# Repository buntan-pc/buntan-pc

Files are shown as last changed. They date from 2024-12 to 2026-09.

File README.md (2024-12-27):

# buntan-pc
BuntanPC は CPU・OS・言語処理系を手作りするプロジェクトです

## プロジェクトの目的
プロジェクトの主目的はオリジナルのコンピュータを作り上げることです。
その過程で CPU、OS、コンパイラ、アセンブラ、リンカ等の作り方を学ぶという副目的もあります。

最終的に BuntanPC で文書作成や Web 閲覧、ロボット制御、プログラミングなどをしたいです。

開発は当面パソコン上で行い、ビルド済みプログラムを転送して実行しますが、
最終的には BuntanPC 上で BuntanPC 向けのアプリを開発したいです。

### マイルストーン
[プロジェクトの中間目標](./doc/milestone.md) には展示会やイベントなどを対象とした開発目標を記します。

## 名前の由来
柑橘類の「文旦（ぶんたん）」と、役割「分担」して作るという意味を掛けています。

PC は Pocket Computer もしくは Personal Computer の略です。
最初はきっとポケコン的な見た目や機能になると思います。
最終的にパソコンが作れたら楽しいですね。

## ライセンス
buntan-pc リポジトリに含まれるソースコードやドキュメントは、別に定めがない限り MIT ライセンスとします。
ライセンス文書 [LICENSE](./LICENSE) にしたがってご利用ください。

## ビルド・実行
実際のビルド方法が決まったらここに書きます。

当面は CPU と OS は BuntanPC Board で動かし、コンパイラ等の言語処理系はパソコン上で動かすことを想定しています。

## BuntanPC Board
BuntanPC を動かすための実機です。
オリジナルのプリント基板を使ったポケコン風の装置で、キーボードや表示装置を持ちます。

プリント基板の提供方法は未定です。決まったら書きます。

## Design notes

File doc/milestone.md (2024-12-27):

# プロジェクトの中間目標

## 2/21 OSC2025 Tokyo/Spring

2/21、22 に開催される [OSC2025 Tokyo/Spring](https://event.ospn.jp/osc2025-spring/) に展示したい。

最低限、次の状態を達成したい！

- BuntanPC 上で何らかの「テキストエディタ」が動き、ファイルを SD カードに保存できる。
  - UART で入出力する前提なので、GUI ではなく CUI あるいは TUI。
  - 最低限は、コマンドラインで 1 行だけ書き込めるもの。
    - 例えば `writestr file.txt foobar hogera` とすると「foobar hogera」とファイルに書かれるとか。
  - Vi のように画面があり、カーソルが動きまわるエディタが作れたら最高。
    - スクロールできない（スクロールせず扱える行数しか扱えない）という仕様もアリ。

可能なら、次の状態も達成したい。

- HEX ファイルを読み取って pmem へ転送し、実行できる。
  - 上述のテキストエディタと組み合わせると、BuntanPC 上でプログラミングできる。
  - ただしハンドアセンブル必須。
- 音楽ファイルを読み取ってスピーカで再生できる。
  - MML のような音楽情報が書かれたファイルを想定。
  - GPIO に接続された圧電スピーカを用いて音楽を再生する。

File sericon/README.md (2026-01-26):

# BuntanPC 用シリアルコンソール

ファイル構成

    controller_rev1/    メインコントローラ（Tang Nano 9K）のソースコードなど

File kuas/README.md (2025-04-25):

= kuas

川合氏作成のアセンブラです。
「kuas」の名前の由来は川合（K）が作った uas 互換アセンブラということです。

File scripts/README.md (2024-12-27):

# scripts

原則として 1 ファイルで完結する、互いに依存しない小物ツール専用のディレクトリです。

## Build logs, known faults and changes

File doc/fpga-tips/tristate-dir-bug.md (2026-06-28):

# USB デバイス検出が動作しないバグ

## 症状

USB の D+/D- を使って USB デバイスの接続を検出しようとしたが、デバイスを接続しても検出されない。

### 具体的説明

次のようなコードを書いたとき、`onboard_led` が点灯しなかった。（LED は 0 出力で点灯）
想定では下位 2 ビットが USB デバイスのスピードに応じて点灯するはずだった。

```veryl
var usb_dp : 'usb logic; // usb_clk に同期した USB D+ 信号
var usb_dm : 'usb logic; // usb_clk に同期した USB D- 信号

var usb_dir_out : 'usb bit;
var usb_dp_out : 'usb logic;
var usb_dm_out : 'usb logic;
assign usb_dp_raw = if usb_dir_out ? usb_dp_out : 1'bz;
assign usb_dm_raw = if usb_dir_out ? usb_dm_out : 1'bz;

enum USBDevSpeed: bit<2> {
  None,
  LS,
  FS,
}
var usb_dev_speed : 'usb USBDevSpeed;

always_ff (usb_clk, usb_rst_n) {
  if_reset {
    usb_dev_speed = USBDevSpeed::None;
  } else if (usb_dm) {
    usb_dev_speed = USBDevSpeed::LS;
  } else if (usb_dp) {
    usb_dev_speed = USBDevSpeed::FS;
  }
}

unsafe (cdc) {
  assign onboard_led = {if ~usb_rst_n ? 4'b0000 : 4'b1111, ~usb_dev_speed};
}
```

## 原因

`usb_dir_out`（USB ライン送受信の方向制御）が未初期化だった。

```veryl
var usb_dir_out : 'usb bit;  // ドライバなし

assign usb_dp_raw = if usb_dir_out ? usb_dp_out : 1'bz;
assign usb_dm_raw = if usb_dir_out ? usb_dm_out : 1'bz;
```

Gowin の合成ツールが未ドライブの `logic` を 0 に最適化せず、`usb_dir_out = 1` であるかのように動作した。その結果 D+/D- が 0 にドライブされた。`usb_dp` と `usb_dm` が 0 として読み出され、`usb_dev_speed` が `None` から更新されなかった。

## 解決策

`usb_dir_out` を明示的に 0 （受信モード）に設定してから D+/D- を読む。
試験的に `assign` で 0 に固定したところ、LED が光るようになった。

```veryl
assign usb_dir_out = 0;
```

## 教訓

双方向 I/O の方向制御信号は必ず明示的に初期化する。
未ドライブの配線/レジスタが合成ツールによって 0 と扱われるとは限らない。

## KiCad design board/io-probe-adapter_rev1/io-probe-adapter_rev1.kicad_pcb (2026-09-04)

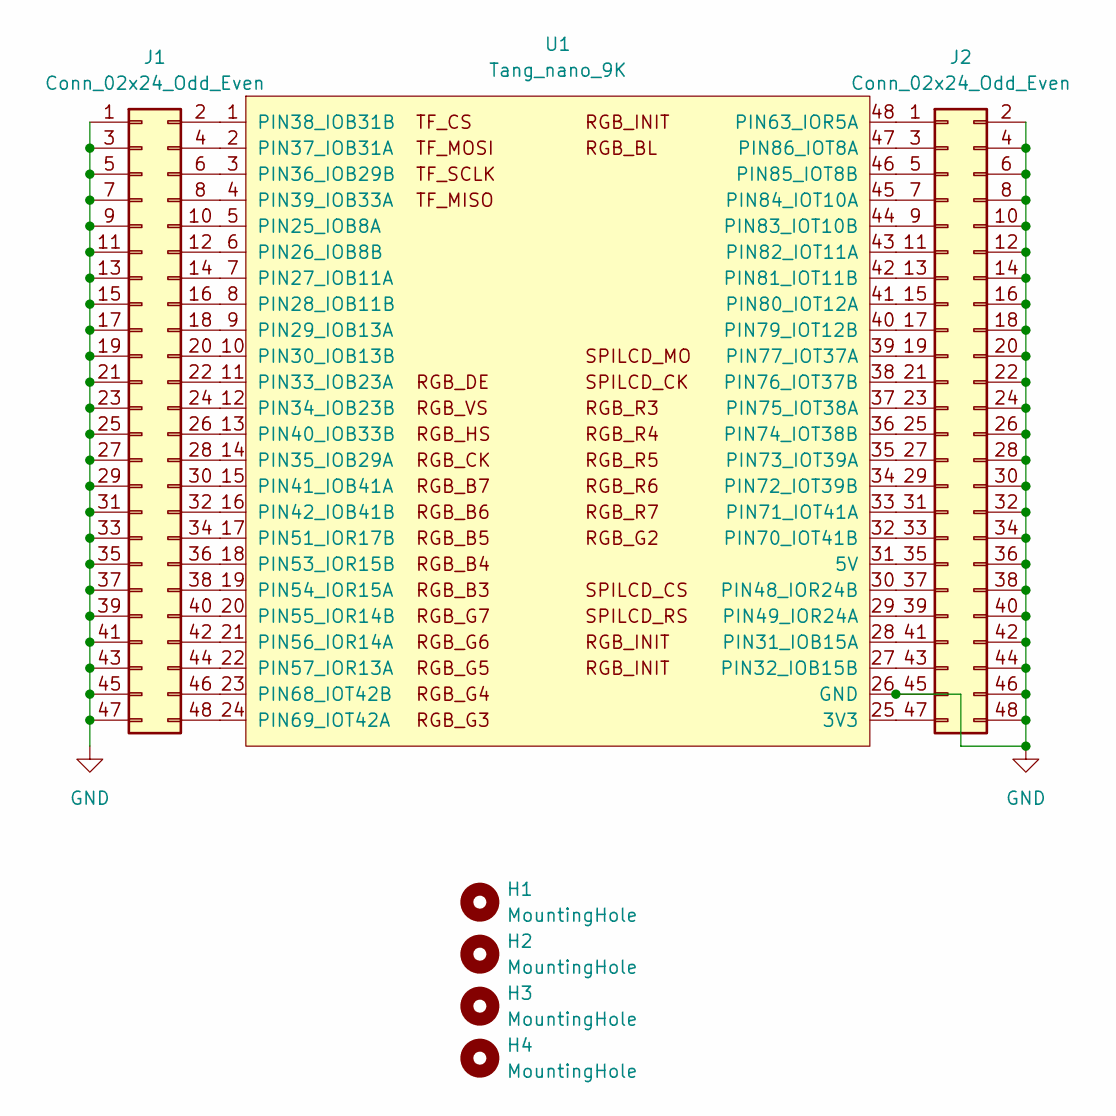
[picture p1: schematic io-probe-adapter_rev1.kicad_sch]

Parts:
H1, H2, H3, H4: MountingHole; MountingHole_3.2mm_M3
J1, J2: Conn_02x24_Odd_Even; PinHeader_2x24_P2.54mm_Vertical
U1: Tang_nano_9K; DIP-48_Tang-Nano-9K

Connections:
GND: J1.1, J1.3, J1.5, J1.7, J1.9, J1.11, J1.13, J1.15, J1.17, J1.19, J1.21, J1.23, J1.25, J1.27, J1.29, J1.31, J1.33, J1.35, J1.37, J1.39, J1.41, J1.43, J1.45, J1.47, J2.2, J2.4, J2.6, J2.8, J2.10, J2.12, J2.14, J2.16, J2.18, J2.20, J2.22, J2.24, J2.26, J2.28, J2.30, J2.32, J2.34, J2.36, J2.38, J2.40, J2.42, J2.44, J2.45, J2.46, J2.48, U1.26 (GND)
unnamed: J1.2, U1.1 (PIN38_IOB31B)
unnamed: J1.4, U1.2 (PIN37_IOB31A)
unnamed: J1.6, U1.3 (PIN36_IOB29B)
unnamed: J1.8, U1.4 (PIN39_IOB33A)
unnamed: J1.10, U1.5 (PIN25_IOB8A)
unnamed: J1.12, U1.6 (PIN26_IOB8B)
unnamed: J1.14, U1.7 (PIN27_IOB11A)
unnamed: J1.16, U1.8 (PIN28_IOB11B)
unnamed: J1.18, U1.9 (PIN29_IOB13A)
unnamed: J1.20, U1.10 (PIN30_IOB13B)
unnamed: J1.22, U1.11 (PIN33_IOB23A)
unnamed: J1.24, U1.12 (PIN34_IOB23B)
unnamed: J1.26, U1.13 (PIN40_IOB33B)
unnamed: J1.28, U1.14 (PIN35_IOB29A)
unnamed: J1.30, U1.15 (PIN41_IOB41A)
unnamed: J1.32, U1.16 (PIN42_IOB41B)
unnamed: J1.34, U1.17 (PIN51_IOR17B)
unnamed: J1.36, U1.18 (PIN53_IOR15B)
unnamed: J1.38, U1.19 (PIN54_IOR15A)
unnamed: J1.40, U1.20 (PIN55_IOR14B)
unnamed: J1.42, U1.21 (PIN56_IOR14A)
unnamed: J1.44, U1.22 (PIN57_IOR13A)
unnamed: J1.46, U1.23 (PIN68_IOT42B)
unnamed: J1.48, U1.24 (PIN69_IOT42A)
unnamed: J2.1, U1.48 (PIN63_IOR5A)
unnamed: J2.3, U1.47 (PIN86_IOT8A)
unnamed: J2.5, U1.46 (PIN85_IOT8B)
unnamed: J2.7, U1.45 (PIN84_IOT10A)
unnamed: J2.9, U1.44 (PIN83_IOT10B)
unnamed: J2.11, U1.43 (PIN82_IOT11A)
unnamed: J2.13, U1.42 (PIN81_IOT11B)
unnamed: J2.15, U1.41 (PIN80_IOT12A)
unnamed: J2.17, U1.40 (PIN79_IOT12B)
unnamed: J2.19, U1.39 (PIN77_IOT37A)
unnamed: J2.21, U1.38 (PIN76_IOT37B)
unnamed: J2.23, U1.37 (PIN75_IOT38A)
unnamed: J2.25, U1.36 (PIN74_IOT38B)
unnamed: J2.27, U1.35 (PIN73_IOT39A)
unnamed: J2.29, U1.34 (PIN72_IOT39B)
unnamed: J2.31, U1.33 (PIN71_IOT41A)
unnamed: J2.33, U1.32 (PIN70_IOT41B)
unnamed: J2.35, U1.31 (5V)
unnamed: J2.37, U1.30 (PIN48_IOR24B)
unnamed: J2.39, U1.29 (PIN49_IOR24A)
unnamed: J2.41, U1.28 (PIN31_IOB15A)
unnamed: J2.43, U1.27 (PIN32_IOB15B)
unnamed: J2.47, U1.25 (3V3)

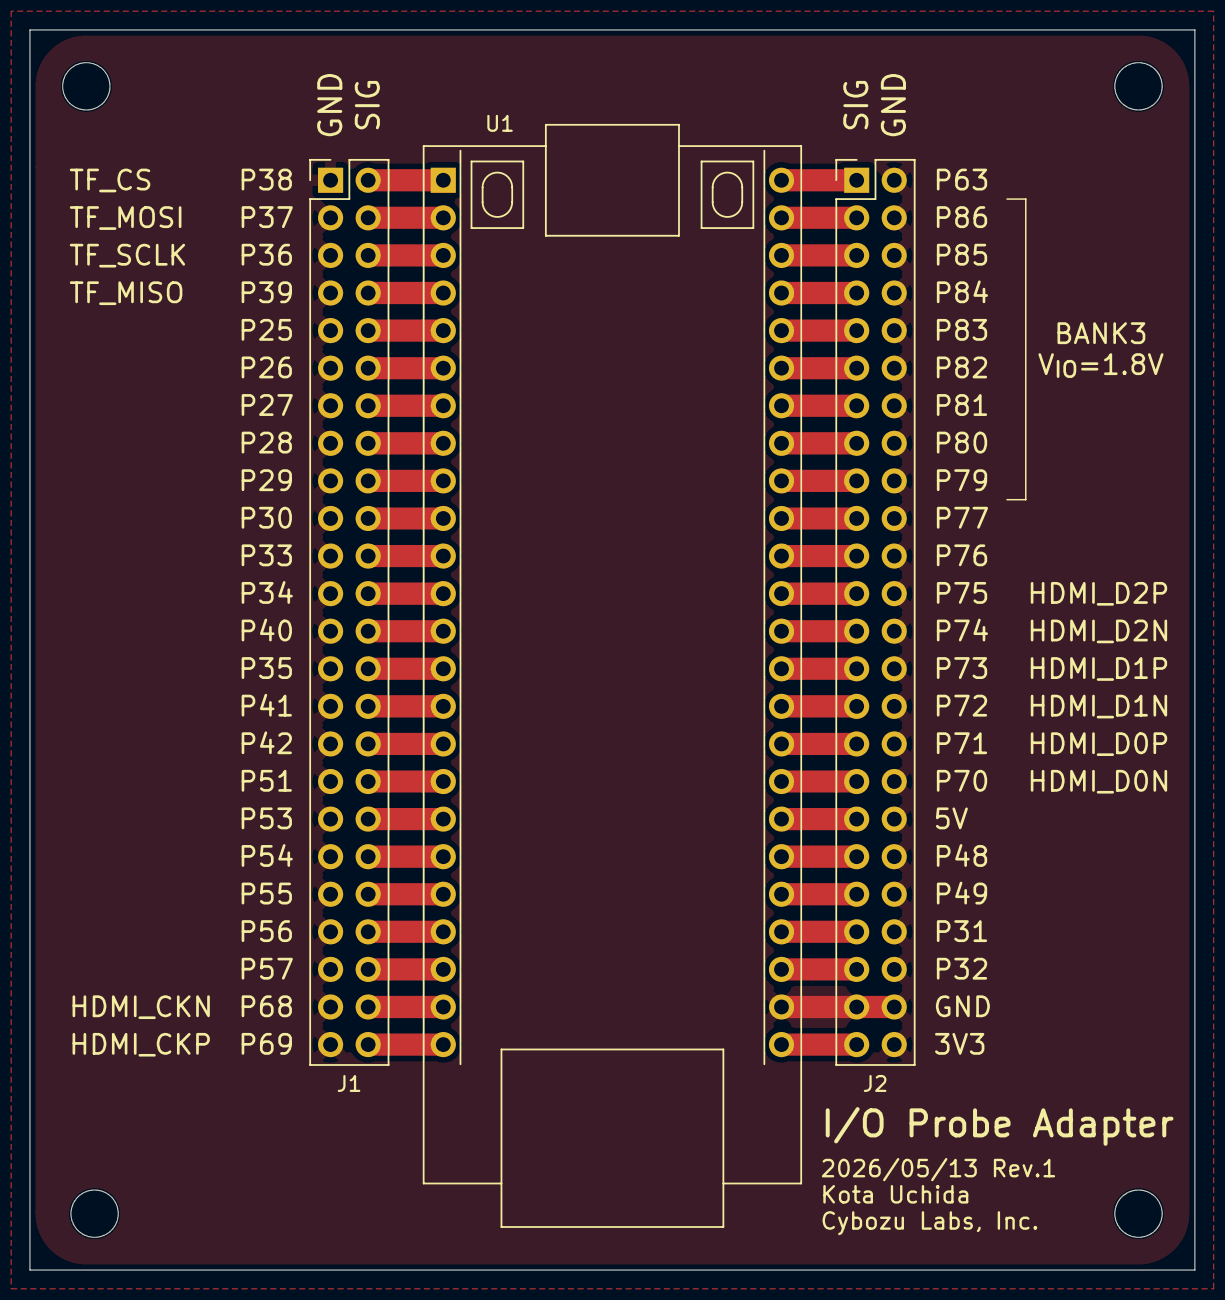
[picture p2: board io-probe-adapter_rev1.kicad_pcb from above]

Board: 2 copper layers, 78.7 x 83.8 mm, 7 parts (0 on the bottom side), 48 nets.

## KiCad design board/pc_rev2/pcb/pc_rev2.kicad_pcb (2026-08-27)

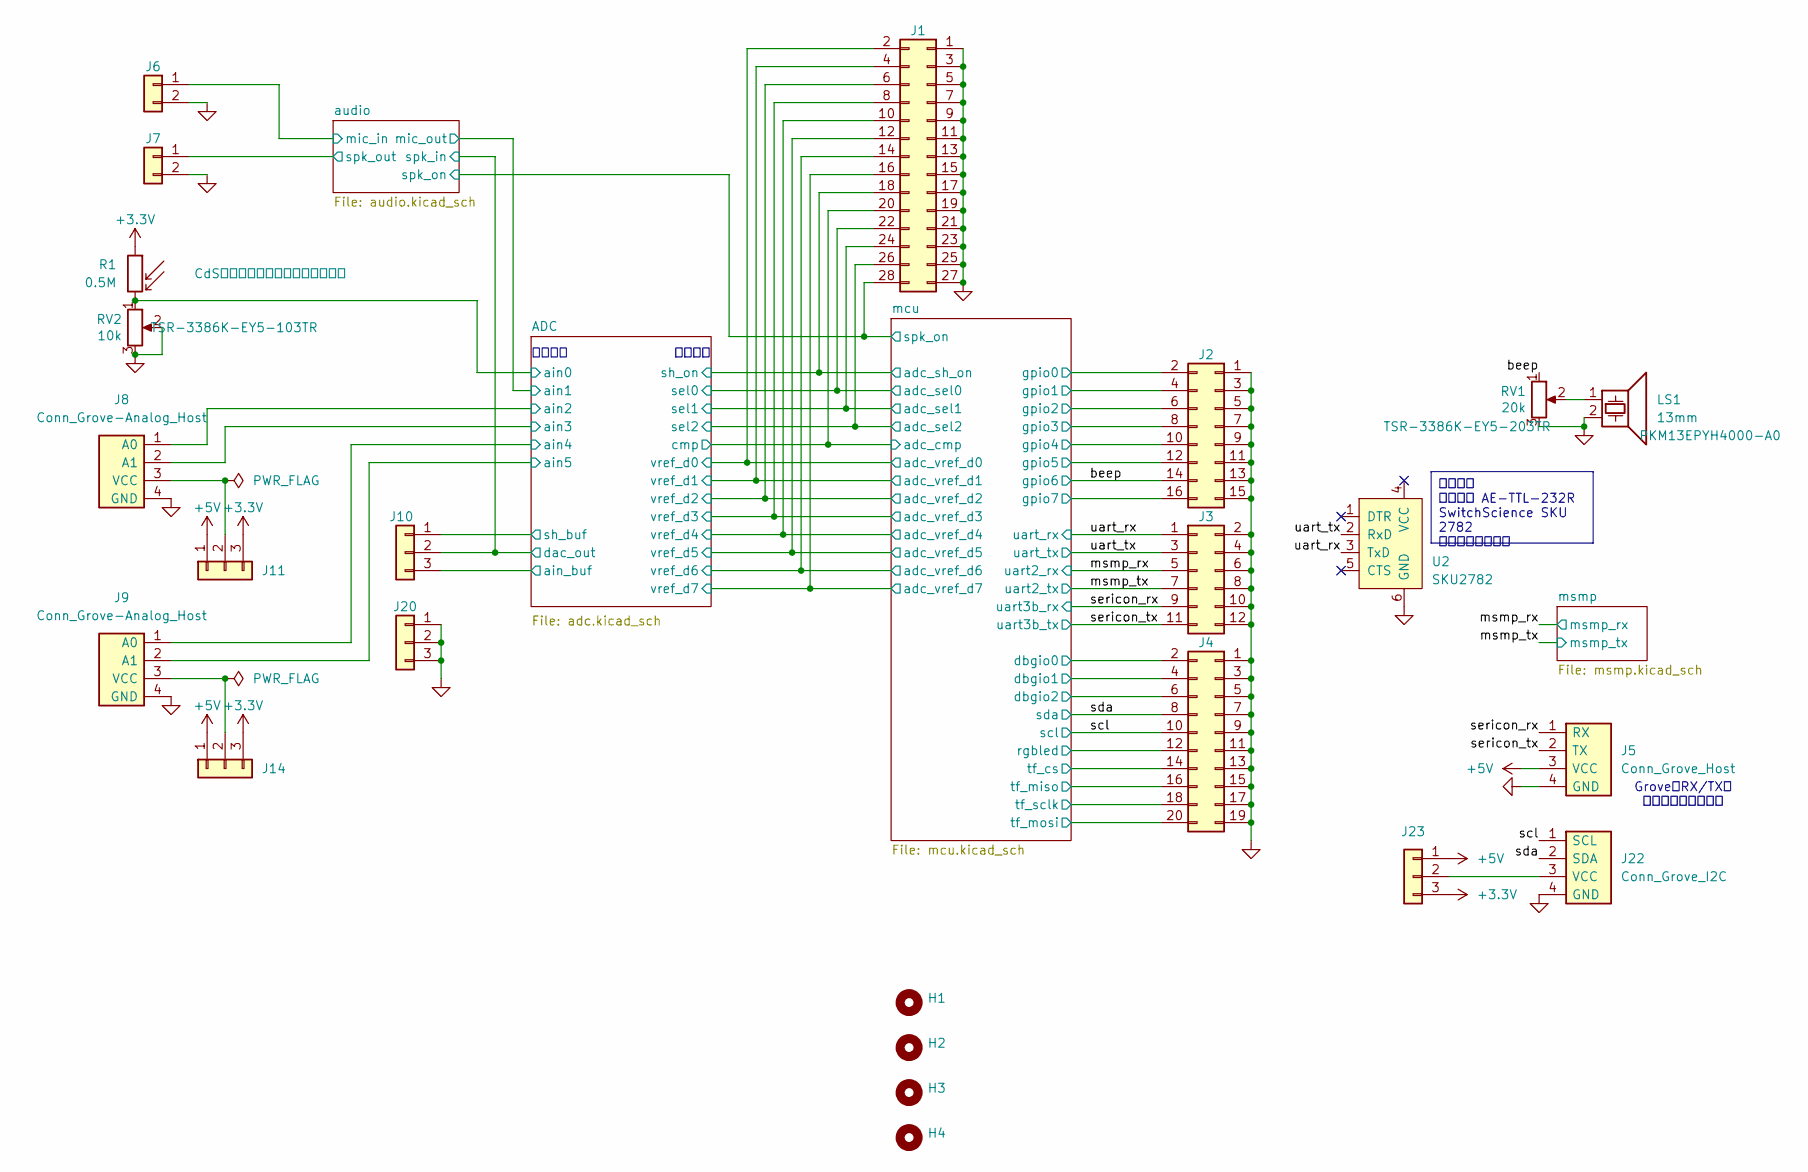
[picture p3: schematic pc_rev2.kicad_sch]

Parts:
H1, H2, H3, H4: MountingHole; MountingHole_3.2mm_M3
J1: Conn_02x13_Odd_Even; PinHeader_2x14_P2.54mm_Vertical
J2: Conn_02x08_Row_Letter_Last; PinHeader_2x08_P2.54mm_Vertical
J3: Conn_02x06_Row_Letter_Last; PinHeader_2x06_P2.54mm_Vertical
J4: Conn_02x10_Row_Letter_Last; PinHeader_2x10_P2.54mm_Vertical
J5: Conn_Grove_Host; Grove_1x04_P2mm_THT_Horizontal
J6, J7: Conn_01x03; JST_XH_S2B-XH-A_1x02_P2.50mm_Horizontal
J8, J9: Conn_Grove-Analog_Host; Grove_1x04_P2mm_THT_Horizontal
J10: Conn_01x05; PinHeader_1x03_P2.54mm_Vertical
J11, J14, J20, J23: Conn_01x03; PinHeader_1x03_P2.54mm_Vertical
J22: Conn_Grove_I2C; Grove_1x04_P2mm_THT_Horizontal
LS1: 13mm; Buzzer_Murata_PKM13EPYH4000-A0_D12.6mm_H6.9mm; Manufacturer PN PKM13EPYH4000-A0
R1: 0.5M; R_LDR_D6.4mm_P3.4mm_Vertical; Manufacturer PN GL5516
RV1: 20k; Potentiometer_Suntan_TSR-3386K_Vertical; Manufacturer PN TSR-3386K-EY5-203TR
RV2: 10k; Potentiometer_Suntan_TSR-3386K_Vertical; Manufacturer PN TSR-3386K-EY5-103TR
U2: SKU2782

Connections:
+3.3V: J11.3, J14.3, J23.3, R1.1; also elsewhere on the board
+5V: J5.3 (VCC), J11.1, J14.1, J23.1; also elsewhere on the board
/ADC/ain0: R1.2, RV2.1; also elsewhere on the board
/ADC/ain2: J8.1 (A0); also elsewhere on the board
/ADC/ain3: J8.2 (A1); also elsewhere on the board
/ADC/ain4: J9.1 (A0); also elsewhere on the board
/ADC/ain5: J9.2 (A1); also elsewhere on the board
/ADC/ain_buf: J10.3; also elsewhere on the board
/ADC/cmp: J1.20; also elsewhere on the board
/ADC/dac_out: J10.2; also elsewhere on the board
/ADC/sel0: J1.22; also elsewhere on the board
/ADC/sel1: J1.24; also elsewhere on the board
/ADC/sel2: J1.26; also elsewhere on the board
/ADC/sh_buf: J10.1; also elsewhere on the board
/ADC/sh_on: J1.18; also elsewhere on the board
/ADC/vref_d0: J1.2; also elsewhere on the board
/ADC/vref_d1: J1.4; also elsewhere on the board
/ADC/vref_d2: J1.6; also elsewhere on the board
/ADC/vref_d3: J1.8; also elsewhere on the board
/ADC/vref_d4: J1.10; also elsewhere on the board
/ADC/vref_d5: J1.12; also elsewhere on the board
/ADC/vref_d6: J1.14; also elsewhere on the board
/ADC/vref_d7: J1.16; also elsewhere on the board
/audio/mic_in: J6.1; also elsewhere on the board
/audio/spk_on: J1.28; also elsewhere on the board
/audio/spk_out: J7.1; also elsewhere on the board
/beep: J2.14, RV1.1; also elsewhere on the board
/mcu/dbgio0: J4.2; also elsewhere on the board
/mcu/dbgio1: J4.4; also elsewhere on the board
/mcu/dbgio2: J4.6; also elsewhere on the board
/mcu/gpio0: J2.2; also elsewhere on the board
/mcu/gpio1: J2.4; also elsewhere on the board
/mcu/gpio2: J2.6; also elsewhere on the board
/mcu/gpio3: J2.8; also elsewhere on the board
/mcu/gpio4: J2.10; also elsewhere on the board
/mcu/gpio5: J2.12; also elsewhere on the board
/mcu/gpio7: J2.16; also elsewhere on the board
/mcu/rgbled: J4.12; also elsewhere on the board
/mcu/tf_cs: J4.14; also elsewhere on the board
/mcu/tf_miso: J4.16; also elsewhere on the board
/mcu/tf_mosi: J4.20; also elsewhere on the board
/mcu/tf_sclk: J4.18; also elsewhere on the board
/msmp_rx: J3.5; also elsewhere on the board
/msmp_tx: J3.7; also elsewhere on the board
/scl: J4.10, J22.1 (SCL); also elsewhere on the board
/sda: J4.8, J22.2 (SDA); also elsewhere on the board
/sericon_rx: J3.9, J5.1 (RX); also elsewhere on the board
/sericon_tx: J3.11, J5.2 (TX); also elsewhere on the board
/uart_rx: J3.1, U2.3 (TxD); also elsewhere on the board
/uart_tx: J3.3, U2.2 (RxD); also elsewhere on the board
GND: J1.1, J1.3, J1.5, J1.7, J1.9, J1.11, J1.13, J1.15, J1.17, J1.19, J1.21, J1.23, J1.25, J1.27, J2.1, J2.3, J2.5, J2.7, J2.9, J2.11, J2.13, J2.15, J3.2, J3.4, J3.6, J3.8, J3.10, J3.12, J4.1, J4.3, J4.5, J4.7, J4.9, J4.11, J4.13, J4.15, J4.17, J4.19, J5.4 (GND), J6.2, J7.2, J8.4 (GND), J9.4 (GND), J20.1, J20.2, J20.3, J22.4 (GND), LS1.2, RV1.3, RV2.2, RV2.3, U2.6 (GND); also elsewhere on the board
unnamed: J8.3 (VCC), J11.2
unnamed: J9.3 (VCC), J14.2
unnamed: J22.3 (VCC), J23.2
unnamed: LS1.1, RV1.2

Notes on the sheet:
デジタル
アナログ
GroveのRX/TXは ホストからみた名前
設計メモ 秋月電子 AE-TTL-232R SwitchScience SKU 2782 どちらも使用可能

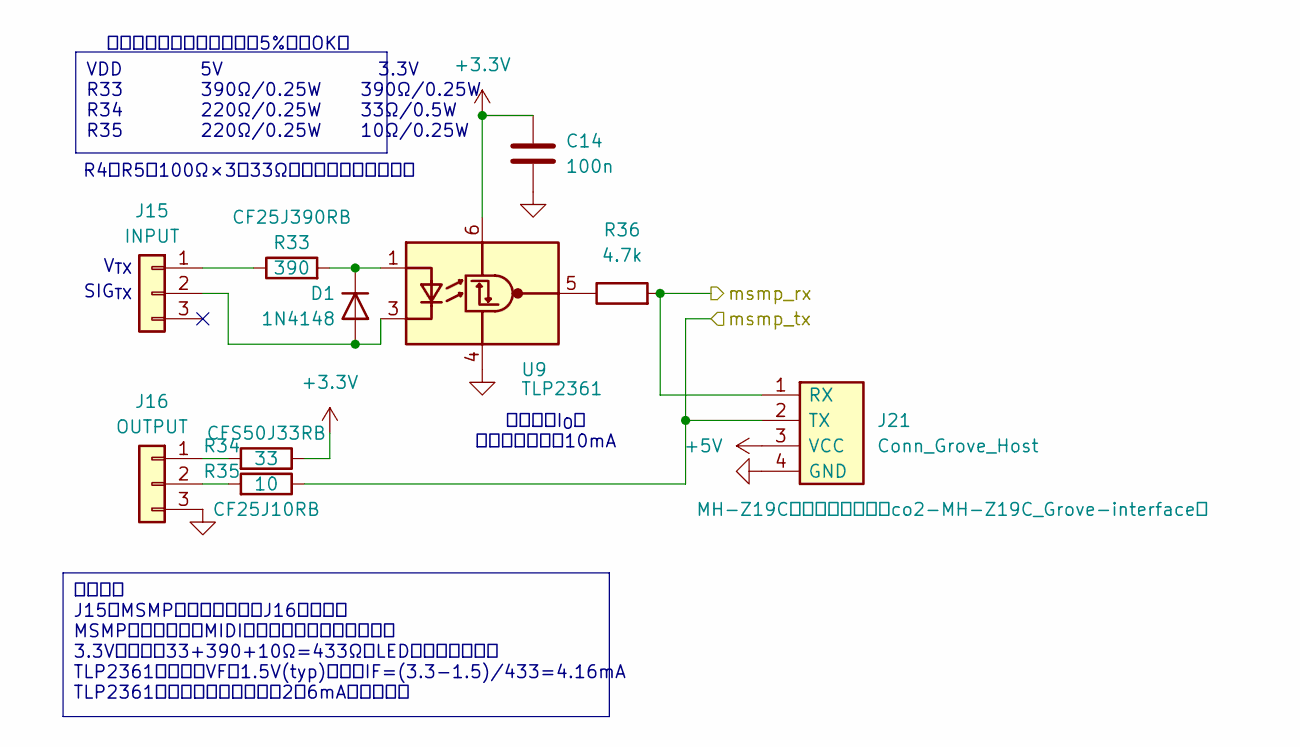
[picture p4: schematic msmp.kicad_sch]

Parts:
C14: 100n; C_0603_1608Metric_Pad1.08x0.95mm_HandSolder
D1: 1N4148; D_DO-34_SOD68_P7.62mm_Horizontal
J15: INPUT; JST_XH_S3B-XH-A_1x03_P2.50mm_Horizontal
J16: OUTPUT; JST_XH_S3B-XH-A_1x03_P2.50mm_Horizontal
J21: Conn_Grove_Host; Grove_1x04_P2mm_THT_Horizontal
R33: 390; R_Axial_CF25_CFS50_L6.3mm_D2.3mm_P7.62mm_Horizontal; Manufacturer PN CF25J390RB
R34: 33; R_Axial_CF25_CFS50_L6.3mm_D2.3mm_P7.62mm_Horizontal; Manufacturer PN CFS50J33RB
R35: 10; R_Axial_CF25_CFS50_L6.3mm_D2.3mm_P7.62mm_Horizontal; Manufacturer PN CF25J10RB
R36: 4.7k; R_0603_1608Metric_Pad0.98x0.95mm_HandSolder
U9: TLP2361; SO-5-6_4.55x3.7mm_P1.27mm

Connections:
+3.3V: C14.1, R34.1, U9.6 (VDD); also elsewhere on the board
+5V: J21.3 (VCC); also elsewhere on the board
/msmp_rx: J21.1 (RX), R36.2; also elsewhere on the board
/msmp_tx: J21.2 (TX), R35.1; also elsewhere on the board
GND: C14.2, J16.3, J21.4 (GND), U9.4 (GND); also elsewhere on the board
unnamed: D1.2 (A), J15.2, U9.3 (K)
unnamed: D1.1 (K), R33.2, U9.1 (A)
unnamed: J15.1, R33.1
unnamed: J16.1, R34.2
unnamed: J16.2, R35.2
unnamed: R36.1, U9.5 (VO)

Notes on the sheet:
SIG_{TX}
出力電流I_{O}の 絶対最大定格は10mA
V_{TX}
抵抗選択表（いずれも精度5%品でOK）
R4、R5は100Ω×3で33Ωを代用する場合に実装
VDD 5V 3.3V R33 390Ω/0.25W 390Ω/0.25W R34 220Ω/0.25W 33Ω/0.5W R35 220Ω/0.25W 10Ω/0.25W
設計メモ J15はMSMP受信コネクタ、J16は送信。 MSMPの物理規格はMIDIと同様のカレントループ。 3.3Vの場合、33+390+10Ω=433ΩでLEDが駆動される。 TLP2361発光部のVFは1.5V(typ)なのでIF=(3.3-1.5)/433=4.16mA TLP2361発光部の推奨動作条件2～6mAに収まる。

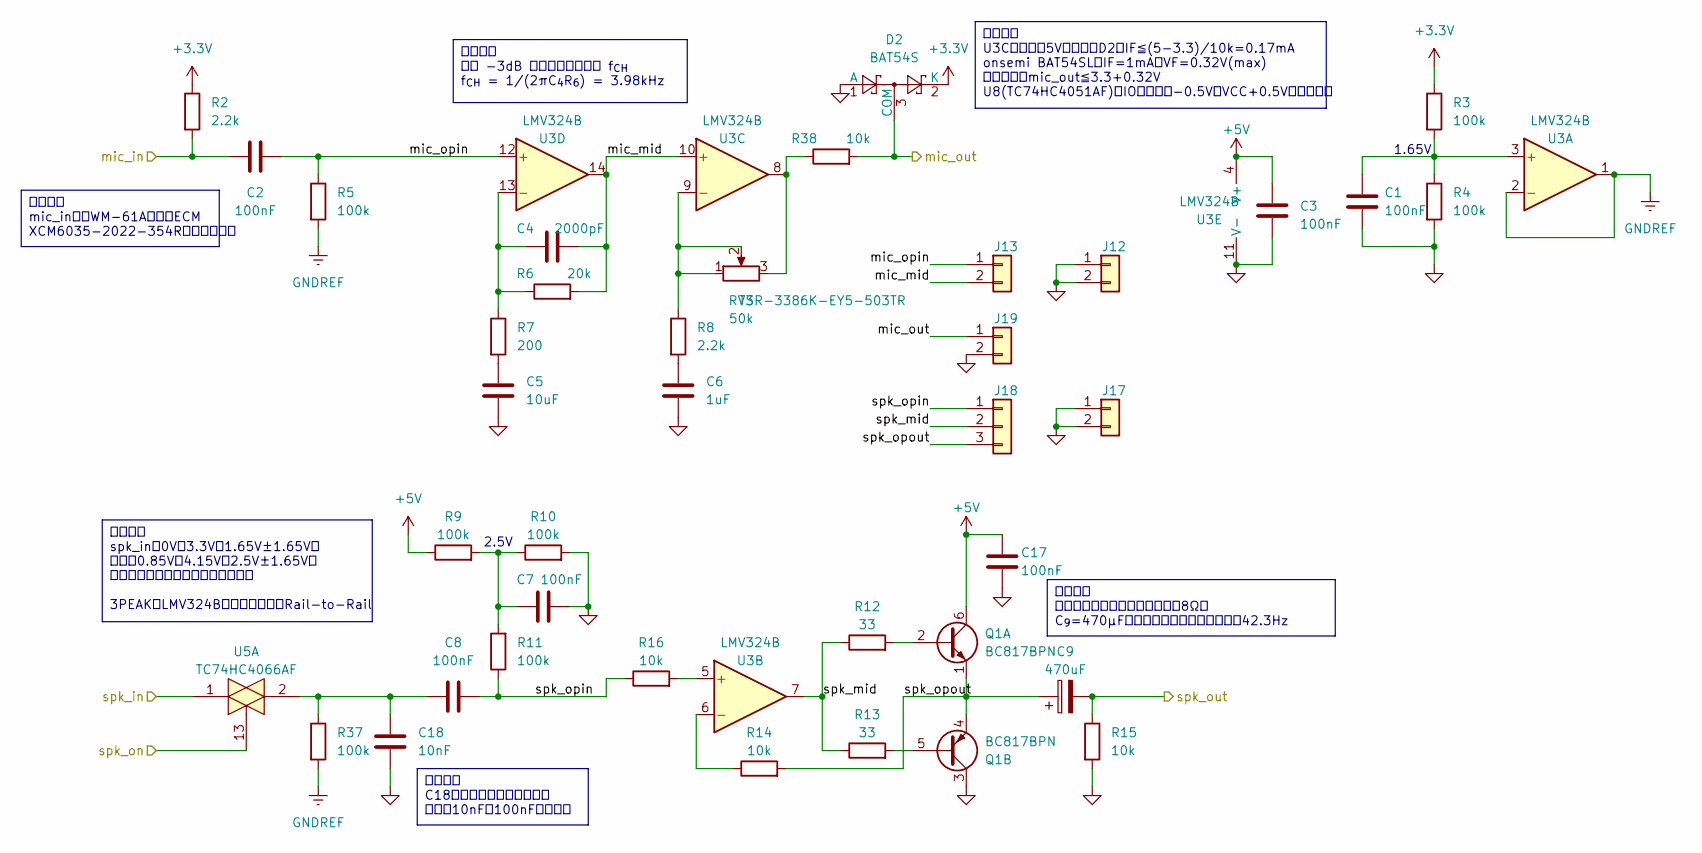
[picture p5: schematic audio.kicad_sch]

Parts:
C1, C2, C3, C7, C8, C17: 100nF; C_0603_1608Metric_Pad1.08x0.95mm_HandSolder
C4: 2000pF; C_0603_1608Metric_Pad1.08x0.95mm_HandSolder
C5: 10uF; C_0603_1608Metric_Pad1.08x0.95mm_HandSolder
C6: 1uF; C_0603_1608Metric_Pad1.08x0.95mm_HandSolder
C9: 470uF; CP_Radial_D8.0mm_P3.50mm
C18: 10nF; C_0603_1608Metric_Pad1.08x0.95mm_HandSolder
D2: BAT54S; SOT-23; Manufacturer PN BAT54SLT1G
J12, J17: GND Pins; PinHeader_1x02_P2.54mm_Vertical
J13, J19: Conn_01x02; PinHeader_1x02_P2.54mm_Vertical
J18: Conn_01x05; PinHeader_1x03_P2.54mm_Vertical
Q1: BC817BPN; SOT-457T
R2, R8: 2.2k; R_0603_1608Metric_Pad0.98x0.95mm_HandSolder
R3, R4, R5, R9, R10, R11, R37: 100k; R_0603_1608Metric_Pad0.98x0.95mm_HandSolder
R6: 20k; R_0603_1608Metric_Pad0.98x0.95mm_HandSolder
R7: 200; R_0603_1608Metric_Pad0.98x0.95mm_HandSolder
R12, R13: 33; R_0603_1608Metric_Pad0.98x0.95mm_HandSolder
R14, R15, R16, R38: 10k; R_0603_1608Metric_Pad0.98x0.95mm_HandSolder
RV3: 50k; Potentiometer_Suntan_TSR-3386K_Vertical; Manufacturer PN TSR-3386K-EY5-503TR
U3: LMV324B; TSSOP-14_4.4x5mm_P0.65mm; Manufacturer PN LMV324B-TR
U5: TC74HC4066AF; SO-14_5.3x10.2mm_P1.27mm

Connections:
+3.3V: D2.2 (K), R2.1, R3.1; also elsewhere on the board
+5V: C3.2, C17.2, Q1.6 (C1), R9.1, U3.4 (V+); also elsewhere on the board
/ADC/dac_out: U5.1; also elsewhere on the board
/audio/mic_in: C2.1, R2.2; also elsewhere on the board
/audio/mic_mid: C4.2, J13.2, R6.2, U3.10 (+), U3.14
/audio/mic_opin: C2.2, J13.1, R5.1, U3.12 (+)
/audio/mic_out: D2.3 (COM), J19.1, R38.2; also elsewhere on the board
/audio/spk_mid: J18.2, R12.1, R13.1, U3.7
/audio/spk_on: U5.13; also elsewhere on the board
/audio/spk_opin: C8.2, J18.1, R11.1, R16.1
/audio/spk_opout: C9.1, J18.3, Q1.1 (E1), Q1.4 (E2), R14.2
/audio/spk_out: C9.2, R15.1; also elsewhere on the board
GND: C1.2, C3.1, C5.2, C6.2, C7.2, C17.1, C18.2, D2.1 (A), J12.1, J12.2, J17.1, J17.2, J19.2, Q1.3 (C2), R4.2, R10.2, R15.2, U3.11 (V-); also elsewhere on the board
GNDREF: R5.2, R37.2, U3.1, U3.2 (-)
unnamed: C5.1, R7.2
unnamed: C6.1, R8.2
unnamed: C7.1, R9.2, R10.1, R11.2
unnamed: C8.1, C18.1, R37.1, U5.2
unnamed: Q1.2 (B1), R12.2
unnamed: Q1.5 (B2), R13.2
unnamed: R38.1, RV3.3, U3.8
unnamed: C1.1, R3.2, R4.1, U3.3 (+)
unnamed: R16.2, U3.5 (+)
unnamed: R14.1, U3.6 (-)
unnamed: R8.1, RV3.1, RV3.2, U3.9 (-)
unnamed: C4.1, R6.1, R7.1, U3.13 (-)

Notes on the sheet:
2.5V
1.65V
設計メモ U3Cの出力が5Vのとき、D2のIF≦(5-3.3)/10k=0.17mA onsemi BAT54SLはIF=1mAでVF=0.32V(max) したがってmic_out≦3.3+0.32V U8(TC74HC4051AF)のIO入力定格-0.5V～VCC+0.5Vを満たす。
設計メモ スピーカーのインピーダンスが8Ω、 C_{9}=470μFのとき、カットオフ周波数は42.3Hz
設計メモ C18はポップノイズ防止用。 無し、10nF～100nFで実験。
設計メモ 高域 -3dB カットオフ周波数 f_{CH} f_{CH} = 1/(2πC_{4}R_{6}) = 3.98kHz
設計メモ spk_inは0V～3.3V（1.65V±1.65V） それを0.85V～4.15V（2.5V±1.65V） にシフトさせ、出力を最大化する。 3PEAKのLMV324Bは入力と出力がRail-to-Rail
設計メモ mic_inにはWM-61A相当のECM XCM6035-2022-354Rを接続予定。

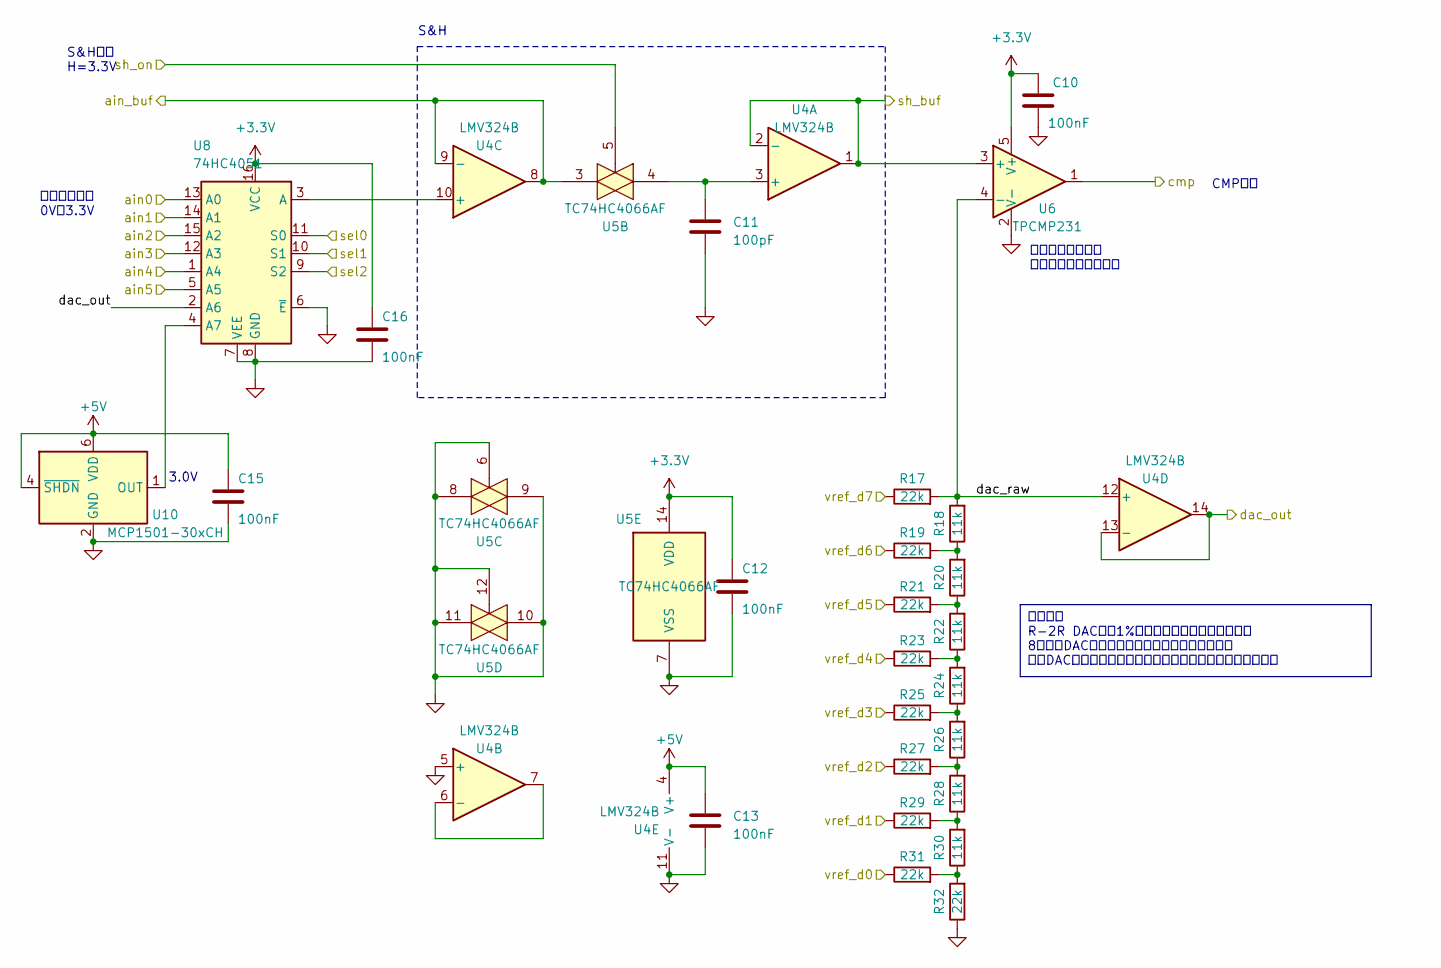
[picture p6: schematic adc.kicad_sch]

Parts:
C10, C12, C13, C15, C16: 100nF; C_0603_1608Metric_Pad1.08x0.95mm_HandSolder
C11: 100pF; C_0603_1608Metric_Pad1.08x0.95mm_HandSolder
R17, R19, R21, R23, R25, R27, R29, R31, R32: 22k; R_0603_1608Metric_Pad0.98x0.95mm_HandSolder
R18, R20, R22, R24, R26, R28, R30: 11k; R_0603_1608Metric_Pad0.98x0.95mm_HandSolder
U4: LMV324B; TSSOP-14_4.4x5mm_P0.65mm; Manufacturer PN LMV324B-TR
U5: TC74HC4066AF; SO-14_5.3x10.2mm_P1.27mm
U6: TPCMP231; SOT-23-5; Manufacturer PN TPCMP231-S5TR
U8: 74HC4051; SOIC-16W_5.3x10.2mm_P1.27mm; Manufacturer PN TC74HC4051AF(EL,F)
U10: MCP1501-30xCH; SOT-23-6

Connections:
+3.3V: C10.1, C12.1, C16.1, U5.14 (VDD), U6.5 (V+), U8.16 (VCC); also elsewhere on the board
+5V: C13.2, C15.1, U4.4 (V+), U10.4 (~SHDN), U10.6 (VDD); also elsewhere on the board
/ADC/ain0: U8.13 (A0); also elsewhere on the board
/ADC/ain2: U8.15 (A2); also elsewhere on the board
/ADC/ain3: U8.12 (A3); also elsewhere on the board
/ADC/ain4: U8.1 (A4); also elsewhere on the board
/ADC/ain5: U8.5 (A5); also elsewhere on the board
/ADC/ain_buf: U4.8, U4.9 (-), U5.3; also elsewhere on the board
/ADC/cmp: U6.1; also elsewhere on the board
/ADC/dac_out: U4.13 (-), U4.14, U8.2 (A6); also elsewhere on the board
/ADC/dac_raw: R17.2, R18.2, U4.12 (+), U6.4 (-)
/ADC/sel0: U8.11 (S0); also elsewhere on the board
/ADC/sel1: U8.10 (S1); also elsewhere on the board
/ADC/sel2: U8.9 (S2); also elsewhere on the board
/ADC/sh_buf: U4.1, U4.2 (-), U6.3 (+); also elsewhere on the board
/ADC/sh_on: U5.5; also elsewhere on the board
/ADC/vref_d0: R31.1; also elsewhere on the board
/ADC/vref_d1: R29.1; also elsewhere on the board
/ADC/vref_d2: R27.1; also elsewhere on the board
/ADC/vref_d3: R25.1; also elsewhere on the board
/ADC/vref_d4: R23.1; also elsewhere on the board
/ADC/vref_d5: R21.1; also elsewhere on the board
/ADC/vref_d6: R19.1; also elsewhere on the board
/ADC/vref_d7: R17.1; also elsewhere on the board
/audio/mic_out: U8.14 (A1); also elsewhere on the board
GND: C10.2, C11.2, C12.2, C13.1, C15.2, C16.2, R32.1, U4.5 (+), U4.11 (V-), U5.6, U5.7 (VSS), U5.8, U5.9, U5.10, U5.11, U5.12, U6.2 (V-), U8.6 (~E), U8.7 (VEE), U8.8 (GND), U10.2 (GND), U10.3 (GND), U10.5 (GND); also elsewhere on the board
unnamed: R18.1, R19.2, R20.2
unnamed: R20.1, R21.2, R22.2
unnamed: R22.1, R23.2, R24.2
unnamed: R24.1, R25.2, R26.2
unnamed: R26.1, R27.2, R28.2
unnamed: R28.1, R29.2, R30.2
unnamed: R30.1, R31.2, R32.2
unnamed: C11.1, U4.3 (+), U5.4
unnamed: U4.6 (-), U4.7
unnamed: U4.10 (+), U8.3 (A)
unnamed: U8.4 (A7), U10.1 (OUT)

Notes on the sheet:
3.0V
S&H制御 H=3.3V
S&H
アナログ入力 0V～3.3V
CMP出力
プッシュプル出力 レールツーレール出力
設計メモ R-2R DACには1%精度のチップ抵抗を用いる。 8ビットDACに本来必要な精度には足りないが、 このDACは動作原理を説明するためのものなので問題無い。

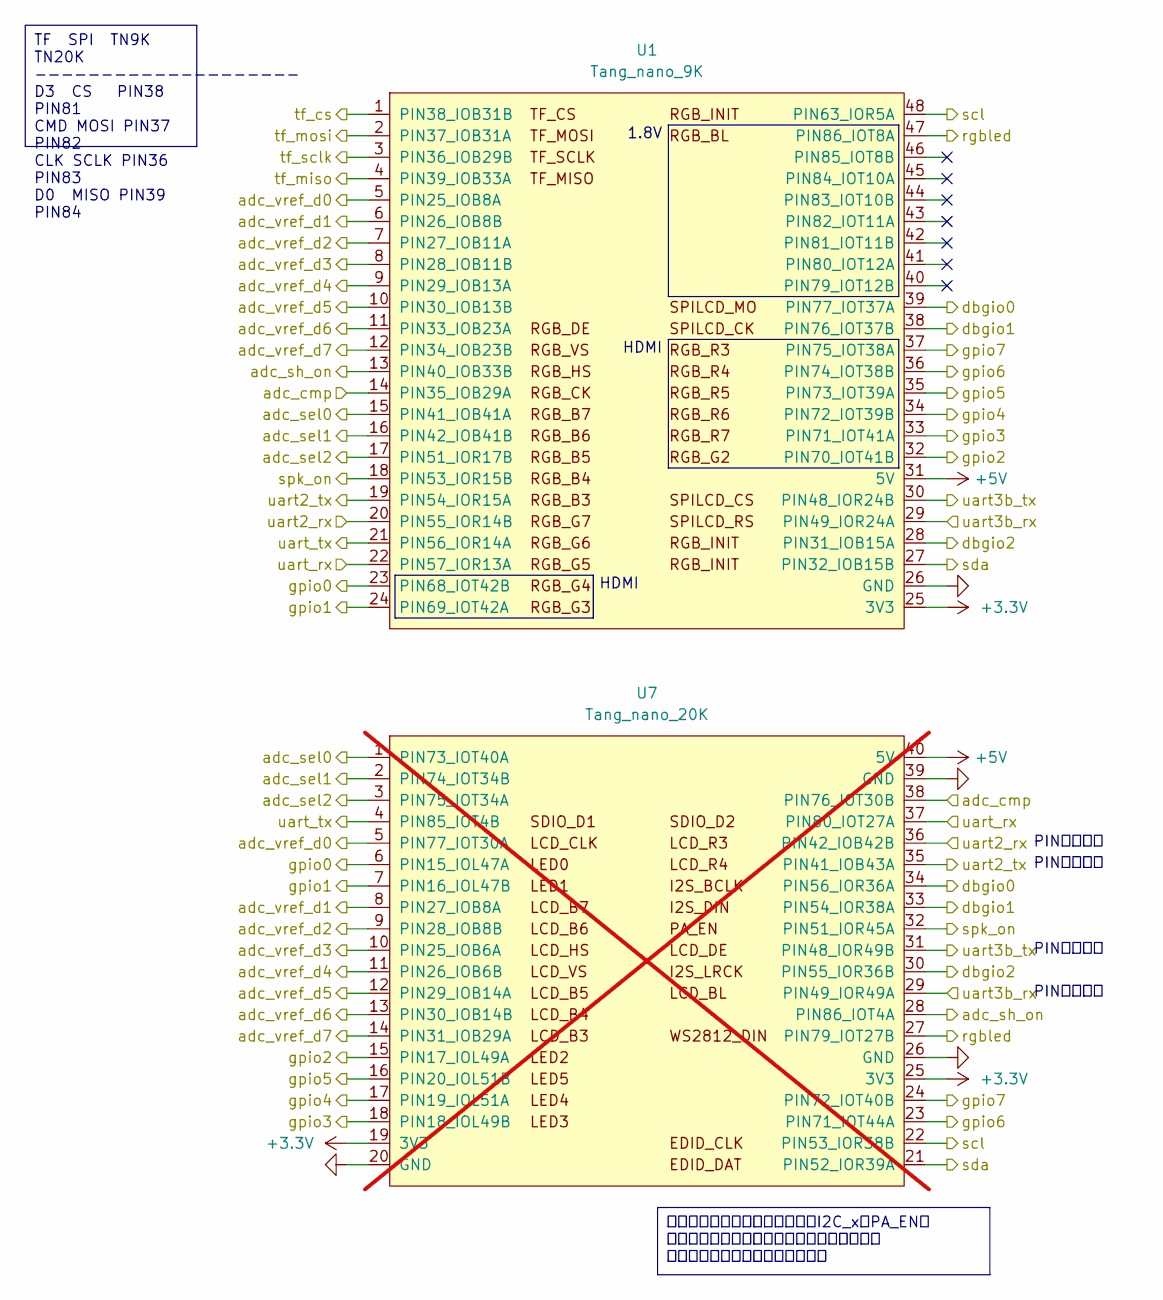
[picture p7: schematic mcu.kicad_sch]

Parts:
U1: Tang_nano_9K; DIP-48_Tang-Nano-9K
U7: Tang_nano_20K; DIP-40_Tang-Nano-20K; not fitted

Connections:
+3.3V: U1.25 (3V3), U7.19 (3V3), U7.25 (3V3); also elsewhere on the board
+5V: U1.31 (5V), U7.40 (5V); also elsewhere on the board
/ADC/cmp: U1.14 (PIN35_IOB29A), U7.38 (PIN76_IOT30B); also elsewhere on the board
/ADC/sel0: U1.15 (PIN41_IOB41A), U7.1 (PIN73_IOT40A); also elsewhere on the board
/ADC/sel1: U1.16 (PIN42_IOB41B), U7.2 (PIN74_IOT34B); also elsewhere on the board
/ADC/sel2: U1.17 (PIN51_IOR17B), U7.3 (PIN75_IOT34A); also elsewhere on the board
/ADC/sh_on: U1.13 (PIN40_IOB33B), U7.28 (PIN86_IOT4A); also elsewhere on the board
/ADC/vref_d0: U1.5 (PIN25_IOB8A), U7.5 (PIN77_IOT30A); also elsewhere on the board
/ADC/vref_d1: U1.6 (PIN26_IOB8B), U7.8 (PIN27_IOB8A); also elsewhere on the board
/ADC/vref_d2: U1.7 (PIN27_IOB11A), U7.9 (PIN28_IOB8B); also elsewhere on the board
/ADC/vref_d3: U1.8 (PIN28_IOB11B), U7.10 (PIN25_IOB6A); also elsewhere on the board
/ADC/vref_d4: U1.9 (PIN29_IOB13A), U7.11 (PIN26_IOB6B); also elsewhere on the board
/ADC/vref_d5: U1.10 (PIN30_IOB13B), U7.12 (PIN29_IOB14A); also elsewhere on the board
/ADC/vref_d6: U1.11 (PIN33_IOB23A), U7.13 (PIN30_IOB14B); also elsewhere on the board
/ADC/vref_d7: U1.12 (PIN34_IOB23B), U7.14 (PIN31_IOB29A); also elsewhere on the board
/audio/spk_on: U1.18 (PIN53_IOR15B), U7.32 (PIN51_IOR45A); also elsewhere on the board
/beep: U1.36 (PIN74_IOT38B), U7.23 (PIN71_IOT44A); also elsewhere on the board
/mcu/dbgio0: U1.39 (PIN77_IOT37A), U7.34 (PIN56_IOR36A); also elsewhere on the board
/mcu/dbgio1: U1.38 (PIN76_IOT37B), U7.33 (PIN54_IOR38A); also elsewhere on the board
/mcu/dbgio2: U1.28 (PIN31_IOB15A), U7.30 (PIN55_IOR36B); also elsewhere on the board
/mcu/gpio0: U1.23 (PIN68_IOT42B), U7.6 (PIN15_IOL47A); also elsewhere on the board
/mcu/gpio1: U1.24 (PIN69_IOT42A), U7.7 (PIN16_IOL47B); also elsewhere on the board
/mcu/gpio2: U1.32 (PIN70_IOT41B), U7.15 (PIN17_IOL49A); also elsewhere on the board
/mcu/gpio3: U1.33 (PIN71_IOT41A), U7.18 (PIN18_IOL49B); also elsewhere on the board
/mcu/gpio4: U1.34 (PIN72_IOT39B), U7.17 (PIN19_IOL51A); also elsewhere on the board
/mcu/gpio5: U1.35 (PIN73_IOT39A), U7.16 (PIN20_IOL51B); also elsewhere on the board
/mcu/gpio7: U1.37 (PIN75_IOT38A), U7.24 (PIN72_IOT40B); also elsewhere on the board
/mcu/rgbled: U1.47 (PIN86_IOT8A), U7.27 (PIN79_IOT27B); also elsewhere on the board
/mcu/tf_cs: U1.1 (PIN38_IOB31B); also elsewhere on the board
/mcu/tf_miso: U1.4 (PIN39_IOB33A); also elsewhere on the board
/mcu/tf_mosi: U1.2 (PIN37_IOB31A); also elsewhere on the board
/mcu/tf_sclk: U1.3 (PIN36_IOB29B); also elsewhere on the board
/msmp_rx: U1.20 (PIN55_IOR14B), U7.36 (PIN42_IOB42B); also elsewhere on the board
/msmp_tx: U1.19 (PIN54_IOR15A), U7.35 (PIN41_IOB43A); also elsewhere on the board
/scl: U1.48 (PIN63_IOR5A), U7.22 (PIN53_IOR38B); also elsewhere on the board
/sda: U1.27 (PIN32_IOB15B), U7.21 (PIN52_IOR39A); also elsewhere on the board
/sericon_rx: U1.29 (PIN49_IOR24A), U7.29 (PIN49_IOR49A); also elsewhere on the board
/sericon_tx: U1.30 (PIN48_IOR24B), U7.31 (PIN48_IOR49B); also elsewhere on the board
/uart_rx: U1.22 (PIN57_IOR13A), U7.37 (PIN80_IOT27A); also elsewhere on the board
/uart_tx: U1.21 (PIN56_IOR14A), U7.4 (PIN85_IOT4B); also elsewhere on the board
GND: U1.26 (GND), U7.20 (GND), U7.26 (GND), U7.39 (GND); also elsewhere on the board

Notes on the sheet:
HDMI
1.8V
PIN番号共通
TF SPI TN9K TN20K -------------------- D3 CS PIN38 PIN81 CMD MOSI PIN37 PIN82 CLK SCLK PIN36 PIN83 D0 MISO PIN39 PIN84
オーディオ機能のためのピン（I2C_xとPA_EN） は面白そうなのでなるべく空けておきたい。 そのためデバッグ用ピンとする。

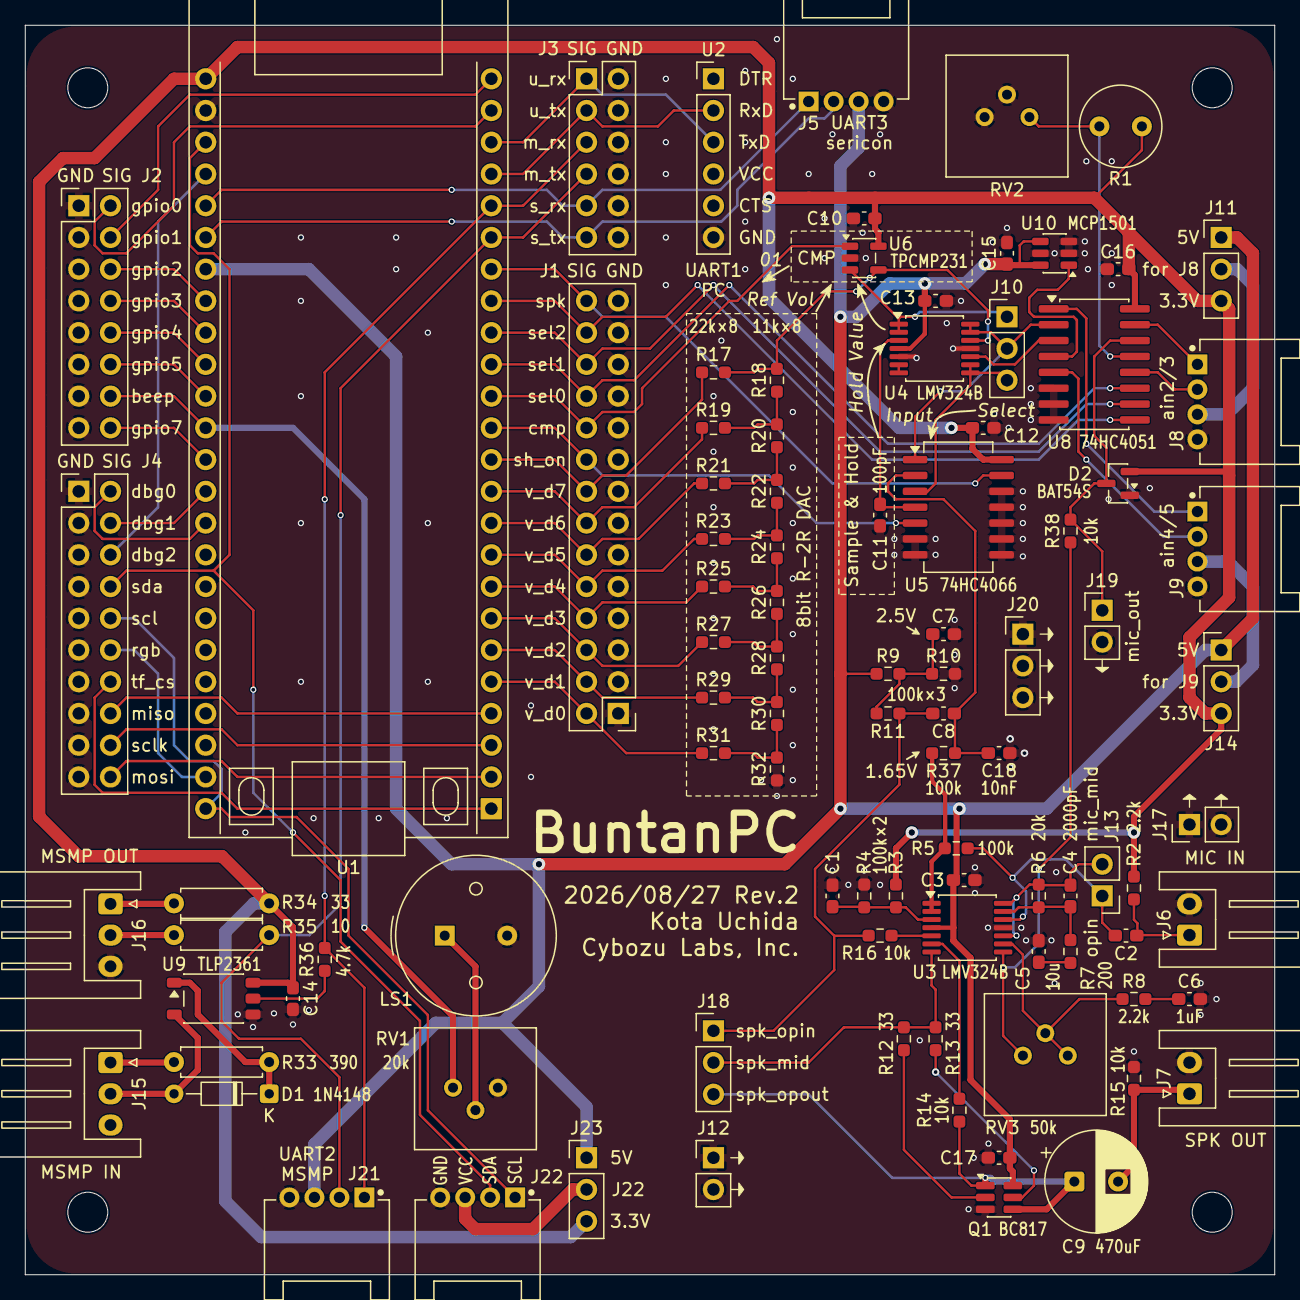
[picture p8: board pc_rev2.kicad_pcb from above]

Board: 2 copper layers, 100.0 x 100.0 mm, 99 parts (0 on the bottom side), 92 nets.

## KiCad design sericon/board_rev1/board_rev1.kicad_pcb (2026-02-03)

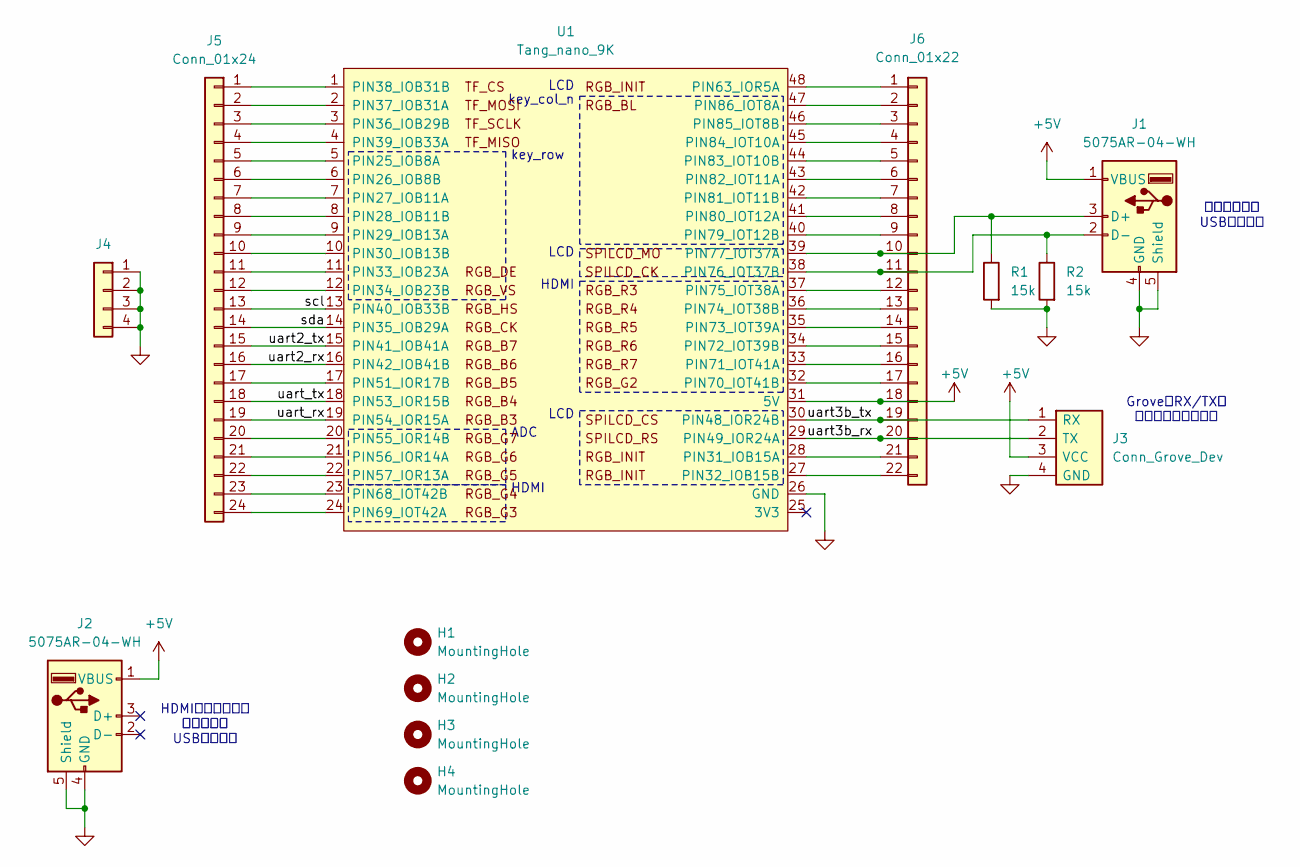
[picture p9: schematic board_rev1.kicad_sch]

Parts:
H1, H2, H3, H4: MountingHole; MountingHole_3.2mm_M3
J1, J2: 5075AR-04-WH; USB_A_Neltron_5075AR-04
J3: Conn_Grove_Dev; Grove_1x04_P2mm_THT_Horizontal
J4: Conn_01x04; PinHeader_1x04_P2.54mm_Vertical
J5: Conn_01x24; PinHeader_1x24_P2.54mm_Vertical
J6: Conn_01x22; PinHeader_1x22_P2.54mm_Vertical
R1, R2: 15k; R_0603_1608Metric_Pad0.98x0.95mm_HandSolder
U1: Tang_nano_9K; DIP-48_Tang-Nano-9K

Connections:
+5V: J1.1 (VBUS), J2.1 (VBUS), J3.3 (VCC), J6.18, U1.31 (5V)
/scl: J5.13, U1.13 (PIN40_IOB33B)
/sda: J5.14, U1.14 (PIN35_IOB29A)
/uart2_rx: J5.16, U1.16 (PIN42_IOB41B)
/uart2_tx: J5.15, U1.15 (PIN41_IOB41A)
/uart3b_rx: J3.2 (TX), J6.20, U1.29 (PIN49_IOR24A)
/uart3b_tx: J3.1 (RX), J6.19, U1.30 (PIN48_IOR24B)
/uart_rx: J5.19, U1.19 (PIN54_IOR15A)
/uart_tx: J5.18, U1.18 (PIN53_IOR15B)
GND: J1.4 (GND), J1.5 (Shield), J2.4 (GND), J2.5 (Shield), J3.4 (GND), J4.1, J4.2, J4.3, J4.4, R1.2, R2.2, U1.26 (GND)
unnamed: J1.3 (D+), J6.10, R1.1, U1.39 (PIN77_IOT37A)
unnamed: J1.2 (D-), J6.11, R2.1, U1.38 (PIN76_IOT37B)
unnamed: J5.1, U1.1 (PIN38_IOB31B)
unnamed: J5.2, U1.2 (PIN37_IOB31A)
unnamed: J5.3, U1.3 (PIN36_IOB29B)
unnamed: J5.4, U1.4 (PIN39_IOB33A)
unnamed: J5.5, U1.5 (PIN25_IOB8A)
unnamed: J5.6, U1.6 (PIN26_IOB8B)
unnamed: J5.7, U1.7 (PIN27_IOB11A)
unnamed: J5.8, U1.8 (PIN28_IOB11B)
unnamed: J5.9, U1.9 (PIN29_IOB13A)
unnamed: J5.10, U1.10 (PIN30_IOB13B)
unnamed: J5.11, U1.11 (PIN33_IOB23A)
unnamed: J5.12, U1.12 (PIN34_IOB23B)
unnamed: J5.17, U1.17 (PIN51_IOR17B)
unnamed: J5.20, U1.20 (PIN55_IOR14B)
unnamed: J5.21, U1.21 (PIN56_IOR14A)
unnamed: J5.22, U1.22 (PIN57_IOR13A)
unnamed: J5.23, U1.23 (PIN68_IOT42B)
unnamed: J5.24, U1.24 (PIN69_IOT42A)
unnamed: J6.1, U1.48 (PIN63_IOR5A)
unnamed: J6.2, U1.47 (PIN86_IOT8A)
unnamed: J6.3, U1.46 (PIN85_IOT8B)
unnamed: J6.4, U1.45 (PIN84_IOT10A)
unnamed: J6.5, U1.44 (PIN83_IOT10B)
unnamed: J6.6, U1.43 (PIN82_IOT11A)
unnamed: J6.7, U1.42 (PIN81_IOT11B)
unnamed: J6.8, U1.41 (PIN80_IOT12A)
unnamed: J6.9, U1.40 (PIN79_IOT12B)
unnamed: J6.12, U1.37 (PIN75_IOT38A)
unnamed: J6.13, U1.36 (PIN74_IOT38B)
unnamed: J6.14, U1.35 (PIN73_IOT39A)
unnamed: J6.15, U1.34 (PIN72_IOT39B)
unnamed: J6.16, U1.33 (PIN71_IOT41A)
unnamed: J6.17, U1.32 (PIN70_IOT41B)
unnamed: J6.21, U1.28 (PIN31_IOB15A)
unnamed: J6.22, U1.27 (PIN32_IOB15B)

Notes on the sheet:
ADC
key_row
GroveのRX/TXは ホストからみた名前
LCD
key_col_n
キーボード用 USBコネクタ
HDMI
HDMIディスプレイ 電源供給用 USBコネクタ

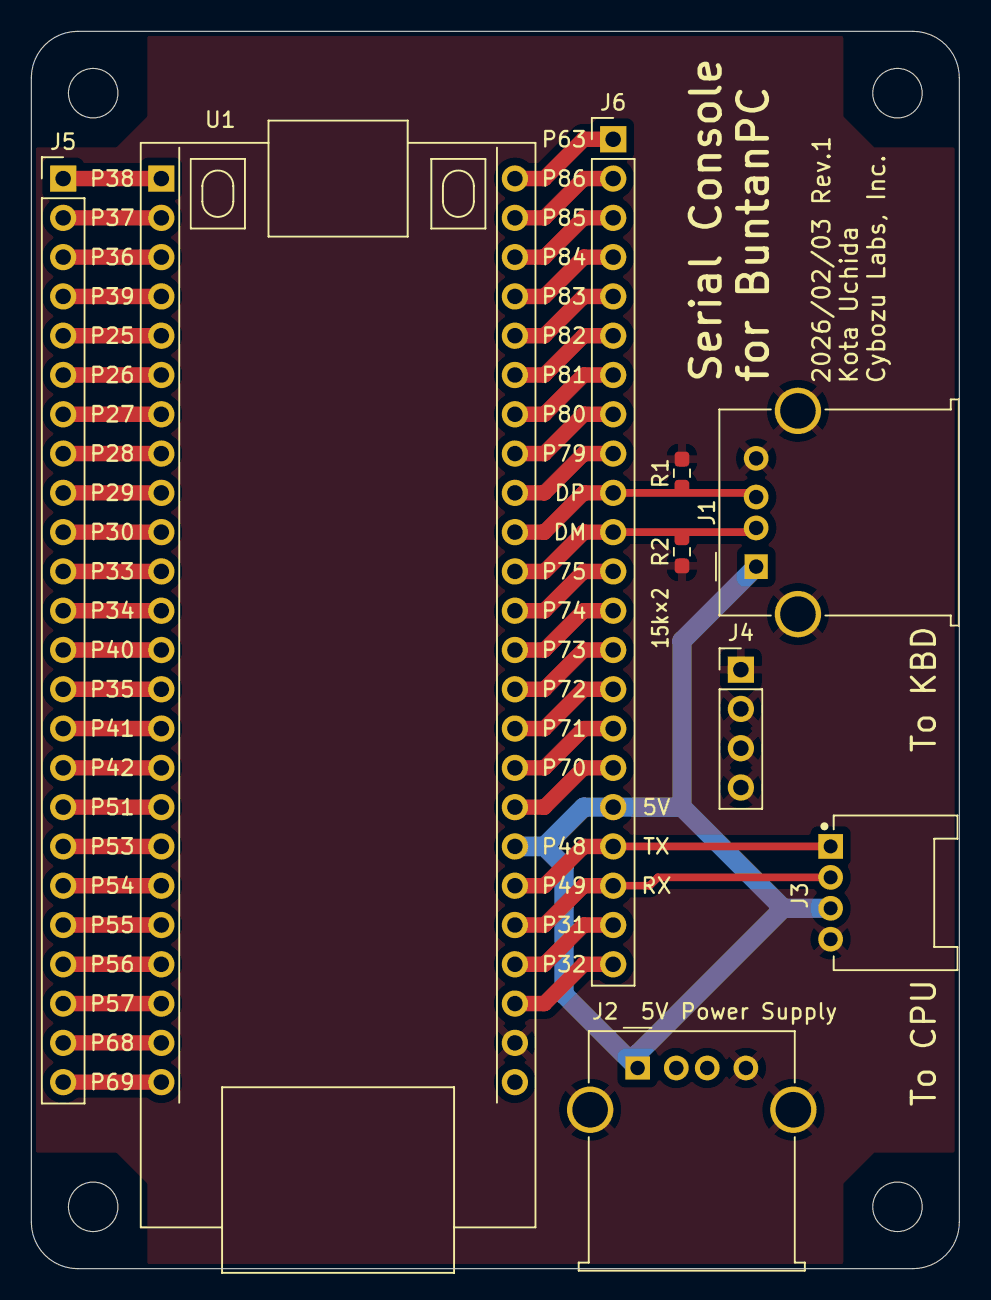
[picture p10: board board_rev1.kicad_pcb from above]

Board: 2 copper layers, 60.0 x 80.0 mm, 13 parts (0 on the bottom side), 47 nets.

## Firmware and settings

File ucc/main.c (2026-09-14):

// SPDX-License-Identifier: MIT
/*
 * Copyright (c) 2024 Kota UCHIDA
 */
#include <assert.h>
#include <ctype.h>
#include <libgen.h>
#include <stdint.h>
#include <stdio.h>
#include <stdlib.h>
#include <string.h>

#include "ast.h"
#include "insn.h"
#include "symbol.h"
#include "token.h"
#include "type.h"

#define INDENT "\t"
#define MAX_STRING 256
#define MAX_LINE (32*1024/2)
#define MAX_SRC_LEN (128*1024)
#define GVAR_OFFSET 0x100
#define MAX_PATHLEN 256

char *src;
void Locate(char *p) {
  char *start = p, *end = p;

  while (src < start && *(start - 1) != '\n') {
    start--;
  }

  while (*end && *end != '\n') {
    end++;
  }

  fprintf(stderr, "%.*s\n", (int)(end - start), start);
  fprintf(stderr, "%*s\n", (int)(p - start + 1), "^");
}

struct JumpLabels {
  int lbreak;
  int lcontinue;
};

struct GenContext {
  struct Scope *scope;
  int frame_size;
  int num_label;
  int num_strings;
  struct Token *strings[MAX_STRING];
  struct JumpLabels jump_labels;
  int num_line;
  struct AsmLine asm_lines[MAX_LINE];
  int print_ast;
  int is_isr; // 現在コンパイルしている関数は ISR である
  int fp_delta; // 可変長引数付きの関数を呼ぶときの FP 変化量
};

int GenLabel(struct GenContext *ctx) {
  return ++ctx->num_label; // L_n ラベルは 1 始まり
}

struct AsmLine *GenAsmLine(struct GenContext *ctx, enum AsmLineKind kind) {
  if (ctx->num_line >= MAX_LINE) {
    fprintf(stderr, "too many asm lines\n");
    exit(1);
  }
  struct AsmLine *l = &ctx->asm_lines[ctx->num_line++];
  l->kind = kind;
  return l;
}

struct Instruction *Insn(struct GenContext *ctx, const char *opcode) {
  struct AsmLine *line = GenAsmLine(ctx, kAsmLineInsn);
  struct Instruction *i = &line->insn;
  SetInsnNoOpr(i, kInsnNormal, opcode);
  return i;
}

struct Instruction *InsnInt(struct GenContext *ctx, const char *opcode, int opr1) {
  struct Instruction *i = Insn(ctx, opcode);
  i->operands[0].kind = kOprInt;
  i->operands[0].val_int = opr1;
  return i;
}

struct Instruction *InsnReg(struct GenContext *ctx, const char *opcode, const char *opr1) {
  struct Instruction *i = Insn(ctx, opcode);
  i->operands[0].kind = kOprReg;
  i->operands[0].val_reg = opr1;
  return i;
}

struct Instruction *InsnRegInt(struct GenContext *ctx, const char *opcode, const char *opr1, int opr2) {
  struct Instruction *i = Insn(ctx, opcode);
  i->operands[0].kind = kOprReg;
  i->operands[0].val_reg = opr1;
  i->operands[1].kind = kOprInt;
  i->operands[1].val_int = opr2;
  return i;
}

struct Instruction *InsnBaseOff(struct GenContext *ctx, const char *opcode, struct BaseOff base_off) {
  struct Instruction *i = Insn(ctx, opcode);
  i->operands[0].kind = kOprBaseOff;
  i->operands[0].val_base_off = base_off;
  return i;
}

struct Instruction *InsnLabelStr(struct GenContext *ctx, const char *opcode, const char *label) {
  struct Instruction *i = Insn(ctx, opcode);
  i->operands[0].kind = kOprLabel;
  i->operands[0].val_label.kind = kLabelStr;
  i->operands[0].val_label.label_str = label;
  return i;
}

struct Instruction *InsnLabel(struct GenContext *ctx, const char *opcode, struct Label *label) {
  struct Instruction *i = Insn(ctx, opcode);
  i->operands[0].kind = kOprLabel;
  i->operands[0].val_label = *label;
  return i;
}

struct Instruction *InsnLabelToken(struct GenContext *ctx, const char *opcode, struct Token *label) {
  struct Instruction *i = Insn(ctx, opcode);
  i->operands[0].kind = kOprLabel;
  i->operands[0].val_label.kind = kLabelToken;
  i->operands[0].val_label.token = label;
  return i;
}

struct Instruction *InsnLabelAuto(struct GenContext *ctx, const char *opcode, enum LabelKind kind, int label) {
  struct Instruction *i = Insn(ctx, opcode);
  i->operands[0].kind = kOprLabel;
  i->operands[0].val_label.kind = kind;
  i->operands[0].val_label.label_no = label;
  return i;
}

struct Instruction *InsnLabelAutoL(struct GenContext *ctx, const char *opcode, int label) {
  return InsnLabelAuto(ctx, opcode, kLabelAutoL, label);
}

struct Instruction *InsnLabelAutoS(struct GenContext *ctx, const char *opcode, const char *base, int label) {
  struct Instruction *i = Insn(ctx, opcode);
  i->operands[0].kind = kOprBaseLabel;
  i->operands[0].val_base_label.base = base;
  i->operands[0].val_base_label.label.kind = kLabelAutoS;
  i->operands[0].val_base_label.label.label_no = label;
  return i;
}

struct Instruction *InsnLabelCase(struct GenContext *ctx, const char *opcode, int label_no, int case_val) {
  struct Instruction *i = Insn(ctx, opcode);
  i->operands[0].kind = kOprLabel;
  i->operands[0].val_label.kind = kLabelCase;
  i->operands[0].val_label.case_.label_no = label_no;
  i->operands[0].val_label.case_.case_val = case_val;
  return i;
}

struct Label *AddLabel(struct GenContext *ctx) {
  struct AsmLine *line = GenAsmLine(ctx, kAsmLineLabel);
  return &line->label;
}

struct Label *AddLabelToken(struct GenContext *ctx, struct Token *t) {
  struct Label *l = AddLabel(ctx);
  l->kind = kLabelToken;
  l->token = t;
  return l;
}

struct Label *AddLabelAutoL(struct GenContext *ctx, int no) {
  struct Label *l = AddLabel(ctx);
  l->kind = kLabelAutoL;
  l->label_no = no;
  return l;
}

struct Label *AddLabelStr(struct GenContext *ctx, const char *s) {
  struct Label *l = AddLabel(ctx);
  l->kind = kLabelStr;
  l->label_str = s;
  return l;
}

struct Label *AddLabelCase(struct GenContext *ctx, int no, int val) {
  struct Label *l = AddLabel(ctx);
  l->kind = kLabelCase;
  l->case_.label_no = no;
  l->case_.case_val = val;
  return l;
}

#define PRINT_NODE_COMMENT(ctx, n, s) \
  do { \
    if ((ctx)->print_ast) { \
      struct AsmLine *l = GenAsmLine((ctx), kAsmLineIndentedComment); \
      snprintf(l->comment, sizeof(l->comment), \
              "Node[%d]: %s", (n->index), (s)); \
    } \
  } while (0)

enum ValueClass {
  VC_CONTENT,
  VC_ADDRESS,
  VC_NO_NEED,
};

void ConvertToBoolean(struct GenContext *ctx) {
  InsnInt(ctx, "push", 0);
  Insn(ctx, "neq");
}

#define GEN_BOOL   0x01u
#define GEN_INTERP 0x02u

// 可能であればアセンブラ内蔵インタープリター上に値を生成する
//#define REQ_INTERP 0x01u
// 自身が kInsnNormal の命令を発行する場合、その直前の命令を kInsnInterpResult にする
//#define REQ_GET_INTERP_RESULT 0x02u

struct Instruction *GetLastInsn(struct GenContext *ctx) {
  struct AsmLine *last_line = &(ctx)->asm_lines[(ctx)->num_line - 1];
  if (last_line->kind != kAsmLineInsn) {
    fprintf(stderr, "cannot get the last instruction: the last line is not kAsmLineInsn.\n");
    exit(1);
  }
  return &last_line->insn;
}

// 命令が 'ld fp+offset' であれば真を返す
int IsLdFpOffset(struct AsmLine *al, int offset) {
  if (al->kind != kAsmLineInsn || strcmp("ld", al->insn.opcode) != 0) {
    return 0;
  }
  struct Operand *operands = al->insn.operands;
  if (operands[0].kind == kOprBaseOff && operands[1].kind == kOprNone &&
      operands[0].val_base_off.base != NULL &&
      strcmp("fp", operands[0].val_base_off.base) == 0 &&
      operands[0].val_base_off.offset == offset) {
    return 1;
  }
  return 0;
}

// 命令が 'add fp,N' であれば真を返す
int IsAddFp(struct AsmLine *al) {
  if (al->kind != kAsmLineInsn || strcmp("add", al->insn.opcode) != 0) {
    return 0;
  }
  struct Operand *operands = al->insn.operands;
  if (operands[0].kind == kOprReg && strcmp("fp", operands[0].val_reg) == 0 &&
      operands[1].kind == kOprInt && operands[2].kind == kOprNone) {
    return 1;
  }
  return 0;
}

// 命令が 'push X+imm' であれば真を返す
int IsPushBaseImm(struct AsmLine *al) {
  if (al->kind != kAsmLineInsn || strcmp("push", al->insn.opcode) != 0) {
    return 0;
  }
  struct Operand *operands = al->insn.operands;
  if (operands[0].kind == kOprBaseOff &&
      operands[1].kind == kOprNone) {
    return 1;
  }
  return 0;
}

// 最終行が push X+imm なら ld/st X+imm に置き換える。そうでなければ lda/sta を発行する。
// store: 0=ld, 1=st
// byt: 0=word, 1=byte
// pop: 1=スタックにデータを残さない
void EmitOptimalLdSt(struct GenContext *ctx, int store, int byt, int pop) {
  struct AsmLine *last_line = &ctx->asm_lines[ctx->num_line - 1];
  if (IsPushBaseImm(last_line)) {
    if (store) {
      last_line->insn.opcode = byt ? "st1" : "st";
    } else {
      last_line->insn.opcode = byt ? "ld1" : "ld";
      if (pop) {
        Insn(ctx, "pop");
      }
    }
  } else {
    Insn(ctx, store ? (byt ? "std1" : "std") : (byt ? "ldd1" : "ldd"));
    if (pop) {
      Insn(ctx, "pop");
    }
  }
}

// 'add fp,N' の N を設定する。N = 0 なら行を削除する。
void SetAddFpValueOrDelete(struct AsmLine *al, int v) {
  if (v != 0) {
    al->insn.operands[1].val_int = v;
  } else {
    al->kind = kAsmLineDeleted;
  }
}

struct BaseOff GetBaseOffset(struct GenContext *ctx, struct Symbol *sym) {
  struct BaseOff base_off = { NULL, sym->offset };
  if (sym->kind == kSymLVar) {
    base_off.base = "fp";
    base_off.offset += ctx->fp_delta;
  } else if (sym->attr & SYM_ATTR_FIXED_ADDR) {
    base_off.base = NULL;
  } else {
    base_off.base = "gp";
  }
  return base_off;
}

unsigned Generate(struct GenContext *ctx, struct Node *node, enum ValueClass value_class, int req_onstack);

void GenVarInit(struct GenContext *ctx, struct Symbol *var) {
  struct Node *init = var->def->rhs;
  if (init == NULL) {
    return;
  }

  struct BaseOff base_off = GetBaseOffset(ctx, var);

  const char *insn_st = "st";
  if ((var->type->kind == kTypeArray && SizeofType(var->type->base) == 1) ||
      (SizeofType(var->type) == 1)) {
    insn_st = "st1";
  }

  if (init->kind != kNodeIList) {
    Generate(ctx, init, VC_CONTENT, 1);
    InsnBaseOff(ctx, insn_st, base_off);
  } else {
    assert(var->type->kind == kTypeArray);
    struct Node *init_val = init->rhs;
    int inc = SizeofType(var->type->base);
    int i = 0;
    for (; init_val; ++i) {
      Generate(ctx, init_val, VC_CONTENT, 1);
      InsnBaseOff(ctx, insn_st, base_off);
      base_off.offset += inc;
      init_val = init_val->next;
    }
    for (; i < var->type->len; ++i) {
      InsnInt(ctx, "push", 0);
      InsnBaseOff(ctx, insn_st, base_off);
      base_off.offset += inc;
    }
  }
}

void GenNodeId(struct GenContext *ctx, struct Symbol *sym, enum ValueClass value_class) {
  assert(sym->type);
  struct BaseOff base_off = GetBaseOffset(ctx, sym);

  if (sym->type->kind == kTypeArray) {
    InsnBaseOff(ctx, "push", base_off);
  } else {
    if (value_class == VC_ADDRESS) {
      InsnBaseOff(ctx, "push", base_off);
    } else {
      // value_class == VC_NO_NEED だとしても ld 命令は発効する。
      // 読み込みの副作用のあるメモリマップトレジスタの可能性がある。
      if (SizeofType(sym->type) == 1) {
        InsnBaseOff(ctx, "ld1", base_off);
      } else {
        InsnBaseOff(ctx, "ld", base_off);
      }
    }
  }
}

// 整数を加算する際の倍率を計算する
size_t CalcAddScale(struct Type *inc_target_type) {
  size_t amount = 1;
  if (inc_target_type->kind == kTypePtr ||
      inc_target_type->kind == kTypeArray) {
    amount = SizeofType(inc_target_type->base);
  }
  return amount;
}
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
int main(int argc, char **argv) {
  int print_ast = 0;
  const char *input_filename = NULL;
  const char *output_filename = "a.s";
  char input_dirname[MAX_PATHLEN] = ".";

  int ret_from_start = 0; // 真なら start 関数は return する
  int global_addr_offset = 0; // グローバル変数のアドレスをずらす量
  for (int i = 1; i < argc; i++) {
    if (strcmp(argv[i], "--ast") == 0) {
      print_ast = 1;
    } else if (strcmp(argv[i], "-o") == 0) {
      i++;
      if (i >= argc) {
        fprintf(stderr, "output file name is not specified\n");
        exit(1);
      }
      output_filename = argv[i];
    } else if (input_filename) {
      fprintf(stderr, "multiple inputs are not supported: '%s'\n", argv[i]);
      exit(1);
    } else if (strcmp(argv[i], "--ret-from-start") == 0) {
      ret_from_start = 1;
    } else if (strcmp(argv[i], "--offset-global-addr") == 0) {
      i++;
      if (i >= argc) {
        fprintf(stderr, "offset value is not specified\n");
        exit(1);
      }
      char *endp = NULL;
      global_addr_offset = strtol(argv[i], &endp, 0);
      if (endp && *endp != '\0') {
        fprintf(stderr, "failed to convert to an integer: '%s'\n", endp);
        exit(1);
      }
    } else {
      input_filename = argv[i];
    }
  }

  if (input_filename == NULL) {
    fprintf(stderr, "no input file\n");
    exit(1);
  }

  FILE *input_file = stdin;
  FILE *output_file = stdout;
  if (strcmp(input_filename, "-") != 0) {
    input_file = fopen(input_filename, "r");
    if (input_file == NULL) {
      fprintf(stderr, "no such file: '%s'\n", input_filename);
      exit(1);
    }
    strncpy(input_dirname, input_filename, MAX_PATHLEN - 1);
    input_dirname[MAX_PATHLEN - 1] = '\0';
    strcpy(input_dirname, dirname(input_dirname));
  }

  src = PreProc(input_file, input_dirname);
  if (input_file != stdin) {
    fclose(input_file);
  }

  struct Scope *global_scope = NewGlobalScope(make_builtin_syms(), global_addr_offset);
  struct ParseContext parse_ctx = {
    global_scope,
    kPPInit,
  };

  Tokenize(src);
  struct Node *ast = Program(&parse_ctx);
  Expect(kTokenEOF);

  if (print_ast) {
    char ast_filename[256];
    if (strcmp(input_filename, "-") == 0) {
      strcpy(ast_filename, "stdin.ast");
    } else {
      snprintf(ast_filename, sizeof(ast_filename), "%s.ast", input_filename);
    }
    FILE *ast_file = fopen(ast_filename, "w");
    for (struct Node *n = ast; n; n = n->next) {
      PrintNode(ast_file, n, 0, NULL);
    }
    fclose(ast_file);
  }

  struct GenContext gen_ctx = {
    parse_ctx.scope,
    0, 0, 0, {}, {-1, -1}, 0, {}, print_ast, 0, 0
  };
  AddLabelStr(&gen_ctx, "start");

  if (strcmp(output_filename, "-") != 0) {
    output_file = fopen(output_filename, "w");
  }
  fprintf(output_file, "section .data\n");
  int gvar_offset = 0;
  for (struct Symbol *sym = global_scope->syms->next; sym; sym = sym->next) {
    if (sym->kind == kSymGVar && (sym->attr & SYM_ATTR_FIXED_ADDR) == 0) {
      // at 属性で配置アドレスを決めたもの（SYM_ATTR_FIXED_ADDR）は無視

      int mem_size = (SizeofType(sym->type) + 1) & 0xfffe;
      gvar_offset += mem_size;

      fprintf(output_file, "%.*s:", sym->name->len, sym->name->raw);
      if (sym->def->rhs == NULL || sym->def->rhs->kind != kNodeInteger) {
        for (int i = 0; i < mem_size; i++) {
          if ((i & 0xf) == 0) {
            fprintf(output_file, "\n" INDENT "db 0");
          } else {
            fprintf(output_file, ",0");
          }
        }
        GenVarInit(&gen_ctx, sym);
      } else { // kind == kNodeInteger
        int val = sym->def->rhs->token->value.as_int;
        fprintf(output_file, "\n" INDENT "db %d,%d", val & 0xff, (val >> 8) & 0xff);
      }
      fprintf(output_file, "\n");
    }
  }

  if (ret_from_start) {
    InsnLabelStr(&gen_ctx, "call", "buntan_main");
    Insn(&gen_ctx, "ret");
  } else {
    InsnLabelStr(&gen_ctx, "call", "buntan_main");
    struct BaseOff base_off = {NULL, 0x06};
    InsnBaseOff(&gen_ctx, "st", base_off); // UART へ出力
    AddLabelStr(&gen_ctx, "fin");
    InsnLabelStr(&gen_ctx, "jmp", "fin");
  }

  for (struct Node *n = ast; n; n = n->next) {
    if (n->kind == kNodeDefFunc) {
      Generate(&gen_ctx, n, VC_NO_NEED, 0);
    }
  }
  //insn_add_fp->operands[1].val_int = global_scope->var_offset;

  for (int i = 0; i < gen_ctx.num_strings; i++) {
    struct Token *tk_str = gen_ctx.strings[i];
    char buf[256];
    fprintf(output_file, "STR_%d: \n" INDENT "db ", i);

    while (tk_str->kind == kTokenString) {
      int len = DecodeStringLiteral(buf, sizeof(buf), tk_str);
      for (int i = 0; i < len; i++) {
        fprintf(output_file, "0x%02x,", buf[i] & 0xff);
      }
      tk_str = tk_str->next;
    }
    fprintf(output_file, "0\n");
  }

  fprintf(output_file, "\nsection .text\n");

  for (int i = 0; i < gen_ctx.num_line; i++) {
    struct AsmLine *line = gen_ctx.asm_lines + i;
    int get_interp_result = 0;

    switch (line->kind) {
    case kAsmLineDeleted:
      break; // 何もしない
    case kAsmLineLabel:
      PrintLabel(output_file, &line->label);
      fprintf(output_file, ":\n");
      break;
    case kAsmLineInsn:
      fprintf(output_file, INDENT);
      get_interp_result = line->insn.kind == kInsnInterpResult &&
                          strcmp(line->insn.opcode, "push") != 0;
      if (line->insn.kind == kInsnInterp || get_interp_result) {
        fprintf(output_file, ".");
      }
      fprintf(output_file, "%s", line->insn.opcode);

      for (int opr_i = 0;
           opr_i < MAX_OPERANDS && line->insn.operands[opr_i].kind != kOprNone;
           opr_i++) {
        struct Operand *opr = line->insn.operands + opr_i;
        fputc(" ,"[opr_i > 0], output_file);
        switch (opr->kind) {
        case kOprNone:
          // pass
        case kOprInt:
          fprintf(output_file, "%d", opr->val_int);
          break;
        case kOprLabel:
          PrintLabel(output_file, &opr->val_label);
          break;
        case kOprReg:
          fprintf(output_file, "%s", opr->val_reg);
          break;
        case kOprBaseOff:
          if (opr->val_base_off.base) {
            fprintf(output_file, "%s+", opr->val_base_off.base);
          }
          fprintf(output_file, "%d", opr->val_base_off.offset);
          break;
        case kOprBaseLabel:
          if (opr->val_base_label.base) {
            fprintf(output_file, "%s+", opr->val_base_label.base);
          }
          PrintLabel(output_file, &opr->val_base_label.label);
          break;
        }
      }
      fprintf(output_file, "\n");

      if (get_interp_result) {
        fprintf(output_file, INDENT "push $top\n");
      }
      break;
    case kAsmLineIndentedComment:
      fprintf(output_file, INDENT "; %s\n", line->comment);
      break;
    case kAsmLineRaw:
      fprintf(output_file, "%s\n", line->raw);
      break;
    }
  }

  // built-in functions
  // addr_t __builtin_write_pmem(addr_t pmem_addr, uint16_t insn_hi, uint16_t insn_lo);
  //fprintf(output_file, "__builtin_write_pmem:\n"
  //                     INDENT "siha\n"
  //                     INDENT "sila\n"
  //                     INDENT "ret\n");

  if (output_file != stdout) {
    fclose(output_file);
  }

  return 0;
}

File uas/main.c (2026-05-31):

// SPDX-License-Identifier: MIT
/*
 * Copyright (c) 2024 Kota UCHIDA
 */
#include <ctype.h>
#include <stdint.h>
#include <stdio.h>
#include <stdlib.h>
#include <string.h>

#define MAX_OPERAND 128
#define MAX_BP 512
#define MAX_LABEL 1024
#define MAX_LINE 512
#define MAX_LINES (16*1024)
#define MAX_SRC_LEN (128*1024)
#define LIST_LEFT_LEN 12

char *src_orig;  // ソースコード全体の先頭
size_t src_len;  // ソースコードのバイト長
char **src_lines; // ソースコード行から行先頭を引くための表
size_t src_lines_len;

// 文字列をすべて小文字にする
void ToLower(char *s) {
  while (*s) {
    *s = tolower(*s);
    s++;
  }
}

struct AsmLine {
  char *label;
  char *mnemonic;
  char *operands[MAX_OPERAND];
  int num_opr;
};

// line をニーモニックとオペランドに分割する
void SplitOpcode(char *line, struct AsmLine *al) {
  al->label = al->mnemonic = NULL;
  al->num_opr = 0;

  if (strtok(line, ";#") == NULL) {
    return;
  }

  char *colon = strchr(line, ':');
  if (colon) {
    al->label = line;
    *colon = '\0';
    line = colon + 1;
  }

  if ((al->mnemonic = strtok(line, " \t\n")) == NULL) {
    return;
  }
  ToLower(al->mnemonic);
  int i;
  for (i = 0; i < MAX_OPERAND; ++i) {
    if ((al->operands[i] = strtok(NULL, ",\n")) == NULL) {
      break;
    }
    al->operands[i] += strspn(al->operands[i], " \t");
    for (char *last = al->operands[i] + strlen(al->operands[i]) - 1;
         last > al->operands[i] && strchr(" \t", *last) != NULL;
         last--) {
      *last = '\0';
    }
  }
  al->num_opr = i;
}

struct LabelAddr {
  const char *label;
  int addr;
};

enum BPType {
  BP_IP_REL12,
  BP_IP_REL14,
  BP_ABS16,
};

struct Backpatch {
  int ip;
  const char *label;
  enum BPType type;
};

void InitBackpatch(struct Backpatch *bp,
                   int ip, const char *label, enum BPType type) {
  bp->ip = ip;
  bp->label = label;
  bp->type = type;
}

void NewBackpatch(struct Backpatch *backpatches, int *num_backpatches,
                  int ip, const char *label, enum BPType bp_type) {
  if (*num_backpatches == MAX_BP) {
    fprintf(stderr, "too many backpatches\n");
    exit(1);
  }
  InitBackpatch(backpatches + (*num_backpatches)++, ip, strdup(label), bp_type);
}

enum AddrBase {
  AB_ZERO,
  AB_FP,
  AB_GP,
  AB_RSVD,
};

// X+imm 形式のオペランドを読み取る
// 戻り値: X の種類を表す数値
enum AddrBase ParseAddrOffset(char *opr, uint16_t *off, struct LabelAddr *labels, int num_labels) {
  char *plus = strchr(opr, '+');
  char *off_s = opr;
  enum AddrBase ab = AB_ZERO;
  if (plus) {
    *plus = '\0';
    off_s = plus + 1;
    ToLower(opr);
    if (strcmp(opr, "z") == 0) {
      ab = AB_ZERO;
    } else if (strcmp(opr, "zero") == 0) {
      ab = AB_ZERO;
    } else if (strcmp(opr, "fp") == 0) {
      ab = AB_FP;
    } else if (strcmp(opr, "gp") == 0) {
      ab = AB_GP;
    } else {
      ab = AB_RSVD;
    }
  }
  if (isdigit(*off_s)) {
    char *endptr;
    *off = strtol(off_s, &endptr, 0);

    if (*endptr) {
      fprintf(stderr, "failed to parse addr offset: '%s'\n", endptr);
      exit(1);
    }
  } else {
    int i = 0;
    for (; i < num_labels; ++i) {
      if (strcmp(labels[i].label, off_s) == 0) {
        break;
      }
    }
    if (i == num_labels) {
      fprintf(stderr, "no such label: '%s'\n", off_s);
      exit(1);
    }
    *off = labels[i].addr;
  }

  return ab;
}

int ExpectFP(char *opr) {
  ToLower(opr);
  if (strcmp(opr, "fp") != 0) {
    return -1;
  }
  return 0;
}

// i 番目のオペランドを文字列として取得
char *GetOperand(char *mnemonic, char **operands, int n, int i) {
  if (n <= i) {
    fprintf(stderr, "too few operands for '%s': %d\n", mnemonic, n);
    exit(1);
  }
  return operands[i];
}

// i 番目のオペランドを long 値として取得（整数変換できなければバックパッチ）
long GetOperandLong(char *operand, struct Backpatch *backpatches,
                    int *num_backpatches, int ip, enum BPType bp_type) {
  char *endptr;
  long value = strtol(operand, &endptr, 0);

  if (endptr == operand) {
    InitBackpatch(backpatches + *num_backpatches, ip, strdup(operand), bp_type);
    (*num_backpatches)++;
    return 0;
  } else if (*endptr) {
    fprintf(stderr, "failed conversion to long: '%s'\n", endptr);
    exit(1);
  }

  return value;
}

// i 番目のオペランドを long 値として取得
long GetOperandLongNoBP(char *operand) {
  char *endptr;
  long value = strtol(operand, &endptr, 0);

  if (*endptr) {
    fprintf(stderr, "failed conversion to long: '%s'\n", endptr);
    exit(1);
  }

  return value;
}

#define GET_STR(i) GetOperand((al->mnemonic), (al->operands), (al->num_opr), (i))
#define GET_LONG(i, bp_type) GetOperandLong(\
    GetOperand((al->mnemonic), (al->operands), (al->num_opr), (i)), \
    (backpatches), &(num_backpatches), (ip), (bp_type))
#define GET_LONG_NO_BP(i) GetOperandLongNoBP(\
    GetOperand((al->mnemonic), (al->operands), (al->num_opr), (i)))

// db 命令のオペランドを解釈し、メモリに書き、バイト数を返す
int DataByte(uint8_t *dmem, char **operands, int num_opr) {
  char *endptr;
  for (int i = 0; i < num_opr; i++) {
    dmem[i] = strtol(operands[i], &endptr, 0);
    if (*endptr) {
      fprintf(stderr, "failed conversion to long: '%s'\n", endptr);
      exit(1);
    }
  }
  return num_opr;
}

// 即値付きロードストア命令
// insn: 機械語テンプレート
// opr: "X+off" 形式の文字列
// mask: 即値のビットマスク
uint32_t GenLoadStoreImm(uint32_t insn, char *operand, uint16_t mask, struct LabelAddr *labels, int num_labels) {
  uint16_t off;
  enum AddrBase ab = ParseAddrOffset(operand, &off, labels, num_labels);
  return insn | (ab << 12) | (mask & off);
}

enum PopReg {
  POP_FP,
  POP_GP,
  POP_ISR,
};

enum PopReg ParsePopReg(char *opr) {
  ToLower(opr);
  if (strcmp(opr, "fp") == 0) {
    return POP_FP;
  } else if (strcmp(opr, "gp") == 0) {
    return POP_GP;
  } else if (strcmp(opr, "isr") == 0) {
    return POP_ISR;
  }

  fprintf(stderr, "invalid register for POP X: '%s'\n", opr);
  exit(1);
}

struct Interp {
  int16_t stack[16];
};

void Push(struct Interp *interp, int16_t v) {
  for (int i = 14; i >= 0; i--) {
    interp->stack[i + 1] = interp->stack[i];
  }
  interp->stack[0] = v;
}

int16_t Pop(struct Interp *interp) {
  int16_t top = interp->stack[0];
  for (int i = 0; i <= 14; i++) {
    interp->stack[i] = interp->stack[i + 1];
  }
  return top;
}

int16_t Top(struct Interp *interp) {
  return interp->stack[0];
}

// ラベルとアドレスの組を設定する。
// ラベルが設定されれば 1 を、ラベルが NULL なら 0 を返す。
int SetLabel(struct LabelAddr *la, const char *label, int addr) {
  if (label) {
    la->label = strdup(label);
    la->addr = addr;
    return 1;
  }
  return 0;
}

// 次行の先頭あるいは EOF を指すポインタを返す。
// src が最終行だった場合 NULL を返す。
char *ReadLine(char *src) {
  char *src_end = src_orig + src_len;
  if (src >= src_end - 1) {
    return NULL;
  }
  src_lines[src_lines_len] = src;
  ++src_lines_len;
  while (src < src_end && *src != '\n') {
    ++src;
  }
  if (src < src_end && *src == '\n') {
    *src = '\0';
    ++src;
  }
  return src;
}
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

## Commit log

2024-11-01 プロジェクトの進め方やライセンス文書などを追加
2024-12-09 コードオーナーを uchan-nos に統一
    後からコードを書く人が増えたらその都度調整する
2024-12-25 OSC2025 Tokyo/Springに向けた開発目標を記載
2024-12-27 ComProcから一式をコピー
    BuntanPCの原型とするために、ComProcプロジェクトから
    コンパイラ、アセンブラ、OS、CPU、CPUボード、幾つかのツールをコピー。
2024-12-27 主要なコードの先頭に著作権表記を追加
2024-12-27 各コンポーネントをルートディレクトリへ移動
2024-12-27 スクリプトファイルに SPDX 識別子を追加
2024-12-27 DOSがLCDを使わないようにしてUARTに特化させる
2024-12-27 UART入力システムコールとサンプルアプリの追加
2025-01-06 Cコンパイラのバグを修正
    - 制御構文で余分な値がスタックに積まれたままになるバグ
    - switch文でdefaultラベルとbreakを使った場合のバグ
    [main.c]
2025-01-06 戻り値無しの関数呼び出しで余分にpopされるバグを修正
2025-01-08 ポインタインクリメントのアドレス加算量のバグ修正
2025-01-08 ファイル読み込みシステムコールとサンプルアプリを追加
2025-01-09 ブロック書き込みシステムコールを追加
2025-01-10 ディレクトリエントリ書き込みのシステムコールを追加
2025-01-10 ファイルの新規作成や追記を試すアプリ fwrite を追加
2025-01-10 アプリがsyscall.hを使うようにする
2025-01-10 コマンドライン引数をアプリに渡す
2025-01-10 コマンド入力時にプロンプトを出す
2025-01-10 同じ値の文字列リテラルを 1 つにまとめる最適化
2025-01-15 UARTでアプリを受信する仕組みを追加
2025-01-16 配列の初期値が足りないときは残りを0で初期化する
2025-01-16 .dataのラベルが1つもない場合に.dataが0バイトになるバグを修正
2025-01-16 送信バイト列に0x55が入っていた場合に送信間隔を空ける
2025-01-20 テキストエディタを追加
2025-01-20 cat がアプリ用 DMEM 領域を壊さないようにする
2025-01-20 ファイル削除コマンド rm を追加
2025-01-20 hexファイルをpmemに転送するコマンドを新設
2025-01-21 DOS起動時にLCDにメッセージを表示＆IPL更新
2025-01-22 プログラムの規模拡大にアセンブラを対応
2025-01-22 UARTと同時にLCDとKBCを利用する
2025-01-22 LCD表示を右矢印に対応させる
2025-01-22 細かいバグ修正
2025-01-22 ラインエディタedを追加
    本家edのコマンドのごく一部のみサポート
2025-01-22 入出力先としてUARTとLCDを選択できるようにする
2025-02-12 IPLを最新化
2025-02-12 OSにキーのエスケープ処理をまかせる
2025-02-12 editをリファクタリング
2025-04-11 ucc: Add option --offset-global-addr
    アセンブラ側で先頭に pmem_len & dmem_len を追加する場合にオフセットが
    4 だけずれるのをコンパイラ側で補正するときに使う想定の仕組み。
2025-04-11 msmp.c を本文無しメッセージの送信に対応させる
2025-04-25 Add kuas assembler, an alternative to uas.
2025-04-25 Update kuas.c - kuas04a相当に更新
    エラー処理改善
    コードを整理
2025-05-07 Update kuas.c - kuas05a相当に更新
2025-08-26 キッチンタイマーアプリを追加
2025-09-27 I2C ディスプレイ制御サンプルを追加
2025-09-27 VCOMが接続できないバグに対応
    WSL2のバージョンが上がったのか、ftdi_sioドライバでは対応できなくなった。
    調査の結果vhci_hcdドライバをロードしたら解決できた。
    see: https://github.com/microsoft/WSL/issues/11795#issuecomment-2235970146
2025-09-27 rename i2ccube -> oledmove
    最初は3Dキューブを表示したかったが、
    現状では単純な図形を上下左右に動かすだけなので改名。
2025-10-03 余分なファイルがブランチに含まれていたので修正削除
2025-10-06 RD, AD を用いたレジスタ割当て（WIP）
2025-10-06 リファクタ（WIP）
2025-10-07 リファクタ一旦完了
2025-10-08 アセンブラ生成途中のRDやADの状態を表示する
2025-10-08 Ershov 数を用いたコード生成シミュレータを追加
2025-10-09 ソースコードを構文解析して木構造を得る
2025-10-09 Ershov 数を用いたコード生成で複文をサポート
2025-10-09 ソースコードから3アドレスコードを得る
2025-10-09 追加し忘れていたファイルを追加
2025-10-09 テンポラリ変数の名前を登場順にする
2025-10-10 3アドレスコードを自動生成か直接与えるかを選択可能にする
2025-10-10 アセンブリ命令の型を ershov と simple で統一
2025-10-10 simple の結果表示を ershov に合わせる
2025-10-20 DOS用アプリをLinux上で動作可能にする
    とりあえずシステムコールのみエミュレーションする
    MMIOのエミュレーションはまだできていない
2026-01-26 シリアルコンソール開発のための環境を整備
2026-01-27 固定のDVI信号を出す（WIP）
    現状、ディスプレイには何も映らない
2026-01-28 黄色一色でディスプレイを塗る
2026-02-03 serial console for BuntanPC の回路と基板を追加
    [board_rev1.kicad_pcb, board_rev1.kicad_sch]
2026-02-03 画面をグラデーションで塗りつぶす
2026-02-05 基板設定を微修正
2026-02-05 デバッグ用ポートを削除
2026-02-05 fclkとpclkのクロックドメインを分ける
    将来の安全性向上のため
2026-02-05 00～7FのASCIIコードに対応した固定の文字列を表示する
2026-02-05 DVI信号生成の部分をモジュールに切り出す
2026-02-05 ソースコードにライセンス名と著作権帰属を表示
2026-02-05 CPUのuart.svをDVI出力回路に移植
    ついでにVerylに書き換え（動作未検証）
2026-02-06 sericonにUARTからの受信機能を追加（動作未検証）
2026-02-06 UART受信のバグを修正
2026-02-07 クロック同士を非同期に指定
    タイミング解析レポートの偽陽性を抑える
2026-02-07 時々UARTから受信ができないバグを修正
2026-02-08 LFで改行する
2026-02-13 sericonのUART受信データ化けを解消
2026-02-13 キャラクタLCD表示を停止＆DOSがUART3のみを使う
2026-02-19 デバッグコードを削除
2026-02-19 大きすぎる unsafe cdc ブロックを無くす
2026-02-20 表示が一周したときに古い内容を表示しない
2026-02-22 デバッグ用ポートの追加
2026-02-22 エスケープシーケンス CSI Pn G に対応
2026-02-23 新しい行に移動したときにRAMを1行分0クリアする
2026-02-23 1文字削除のエスケープシーケンスに対応
2026-02-23 マーカー方式の痕跡を削除
2026-02-24 エスケープシーケンス解析をリファクタ
2026-02-24 USB-UARTによるデバッグを可能にする
2026-02-24 DECSET, DECSTBMを認識
2026-02-24 edit.cが使うエスケープシーケンスに対応（WIP）
2026-02-26 カーソル移動に対応
    ついでにICHも一部実装
    ICHは本来右にずらす処理が必要だが、まだやっていない
2026-03-29 人間が操作するオセロプログラムを追加
2026-03-29 1手のみ先読みの貪欲法オセロAIを搭載
2026-03-29 uccでコンパイル可能にするために変更
2026-03-29 BuntanPCアプリのエントリポイントをbuntan_mainへ変更
    Linux上でも同じコードを動かすために
    標準Cと競合しない名前にした
2026-04-22 ucc: PrintNodeがn->tokenを参照する前にNULLチェックするように
2026-04-22 ucc: main関数をbuntan_mainに移行したがtestがmainを要求して失敗していたので修正
2026-04-27 uasにリストファイル生成機能を追加
2026-04-27 dos.lstの生成ルールを追加
2026-04-30 バックパッチ後の機械語をリストファイルへ出力する
2026-04-30 オセロAIを追加（WIP）
2026-04-30 エスケープシーケンスを使ってオセロ盤面を見やすく表示
2026-04-30 盤面評価関数を実装（WIP）
2026-04-30 AIの思考時間を計測
2026-04-30 初期盤面に誤って石が描画されるバグを修正
2026-04-30 エスケープシーケンスCNL,CPL,ELを追加サポート
2026-04-30 CPUの単体テストのビルドが通るように修正
    ただし、一部のテストは失敗する
2026-04-30 CPUの単体テストを修正
2026-04-30 FPの最小値を保持するレジスタFPMINを追加
2026-04-30 min-maxで2手先読み
2026-04-30 othello.cにスタック使用量測定コードを追加
2026-04-30 pc_rev1をコマンドラインでビルド可能にする
2026-04-30 RAM推論失敗の修正中（WIP）
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2026-04-30 コメント修正
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2026-04-30 CPUの動作周波数を20MHzに落とす & uasバグ修正
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2026-05-08 添字が 0 のときに無駄に add を発行しない
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2026-05-08 石の返し方のバグを修正
2026-05-08 uasバグ修正
    リストファイルを指定していない場合にSIGSEGVになるバグ
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2026-05-08 AIが石を置けるのにパスするバグを修正
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2026-05-23 デバッグ情報を時分割で出力（4 clocks = 1 word）
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2026-05-26 1024の倍のアドレスのときに正しく動かないバグを修正
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2026-05-31 CPUが動作しないバグを修正
2026-06-01 タイミング制約を満たすリファクタ
    Fmax が 26.898MHz から 27.212MHz に改善
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2026-06-08 MMIOの単体テストが成功するように修正
2026-06-09 UART 送信に uart モジュールを利用する
2026-06-16 無駄な add fp,0 を出力しない
2026-06-17 可変長引数のバグ修正（WIP）
    関数ポインタの引数に型を指定できるようにする
2026-06-17 引数が複数回参照されるときに誤って最適化されてしまうバグを修正
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2026-06-22 buntan_printf の実装とテストを追加
    %c, %d, %X にのみ対応
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2026-07-02 Veryl 0.20.2 対応
    誤って 0 ビット幅の即値を書いてしまっていたのを正しく修正。
    Veryl 0.20.0 以前だとエラーではなかったため気付いてなかった。
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2026-07-17 Boot Interface を探して SET_PROTOCOL する
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2026-07-25 キーボード認証バグ修正
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2026-08-07 BuntanPC Rev.2 の回路を追加
    [adc.kicad_sch, audio.kicad_sch, pc_rev2.kicad_pcb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]
2026-08-07 MSMP-IFを追加、スピーカ出力をOFFにする仕組みを追加（WIP）
    [adc.kicad_sch, audio.kicad_sch, mcu.kicad_sch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]
2026-08-08 ADCの8ch化＆スピーカーミュートの仕組み変更
    [adc.kicad_sch, audio.kicad_sch, mcu.kicad_sch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]
2026-08-25 諸々改良＆基板デザイン（WIP）
    [adc.kicad_sch, audio.kicad_sch, mcu.kicad_sch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]
2026-08-25 Rev.2基板のシルク印刷を整える
    [pc_rev2.kicad_pcb]
2026-08-26 ポップノイズ防止用コンデンサ追加＆シルク微修正
    [audio.kicad_sch, pc_rev2.kicad_pcb]
2026-08-27 I2C用Groveコネクタを追加
    [mcu.kicad_sch, pc_rev2.kicad_pcb, pc_rev2.kicad_sch]
2026-08-27 オペアンプ入力保護抵抗を追加
    [audio.kicad_sch, pc_rev2.kicad_pcb]
2026-09-04 回路図の配置を微修正
    [audio.kicad_sch]
2026-09-04 Tang Nano 9K のIOにロジックアナライザを接続するための基板を作成
    [io-probe-adapter_rev1.kicad_pcb, io-probe-adapter_rev1.kicad_sch]
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2026-09-16 Revert "LFの代わりにCNLを発行する（スクロール防止）"
    This reverts commit a3f2ca9a538029d5b1de96fae6e5fc86e88fd2aa.
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2026-10-04 USB関連の回路タイミング修正
2026-10-04 複数キーを押したときに誤検出するバグを修正
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2026-10-16 UARTの受信完了と読み込みが同タイミングの場合のバグを修正
2026-10-16 Improve ADC timing path
2026-10-16 Synchronize ADC reset release to clk125
2026-10-16 コマンド履歴モードを抜けたときにプロンプトに文字が残るバグを修正
2026-10-16 コマンド履歴を修正して実行する際のバグを修正
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2026-10-18 割り込み復帰時に1つ前の命令に戻ってしまうバグを修正
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2026-11-13 DOSの履歴機能のバグを修正
